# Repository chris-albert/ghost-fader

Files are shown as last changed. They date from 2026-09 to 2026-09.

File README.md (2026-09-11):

# Ghost Fader

USB-MIDI-controlled volume and pan for two balanced 1/4" line channels. Balanced in, always-balanced out, one input becomes stereo automatically. Bus-powered Seeed XIAO RP2040 plus a 2x2 gain matrix of PGA2310 attenuators. Revision D: USB only, no DIN jack, no DC jack; the audio side is galvanically isolated from the computer. A TI ISO7762F carries the four control lines and two sense lines across a split in the ground pours, the DC-DC module is the only power path across it, and a 78L05 makes the PGA logic supply on the audio side. About $6 of parts on top of rev C (XIAO RP2040, Traco TBA 2-0522).

The full schematic package (block diagram, five sheets, level budget, USB power budget, MIDI map, build order) is published at https://chris-albert.github.io/ghost-fader/ (source: `docs/index.html`). This file is the short version.

## Signal chain

```
J1/J2 TRS in -> THAT 1246 (bal->SE, -6 dB) -> 2x PGA2310 (2x2 matrix, 4 gains)
             -> OPA1642 summers (non-inverting, x2) -> THAT 1646 (SE->bal, +6 dB) -> J3/J4 TRS out
```

- Net gain balanced-to-balanced is 0 dB at PGA code 192. PGA range is +31.5 to -95.5 dB in 0.5 dB steps, plus hard mute.
- A TS plug on an input grounds the ring, so unbalanced sources need no switch. A TS plug on an output is handled by the cross-coupled 1646.
- Plug sense: each input jack's ring-normal contact is pulled up to +5VA by 100 k and read by the XIAO (D0, D1) through the isolator. Tip-normal is grounded.
- Matrix: U3 carries the direct paths (L->L, R->R), U4 the cross paths (L->R, R->L). Mono mode pans the L input across both outputs with a constant-power law; stereo mode uses balance.

## Power

Everything runs from the USB cable. There is no external power supply, DC jack or wall adapter. The XIAO's 5V pin is USB VBUS straight through, so it exports the bus 5 V. That feeds PS1, a small isolated 5 V -> +/-12 V DC-DC converter soldered to the board (Traco TBA 2-0522, 2 W, SIP-7), for the analog stages. The PGA2310 logic supply and the audio side of the isolator run on +5VA, made from +12 V by U10, a 78L05, so nothing on the audio side references the USB ground.

PS1 is unregulated: the rails follow the USB voltage and the load, from about +/-11 V on a sagging port to about +/-14 V at 5.25 V and light load. Every part on the rails is rated for that (the PGA2310 absolute maximum is 16 V, which is why the +/-15 V TBA 2-0523 is not used). Headroom at +/-12 V is about 2 dB less than on +/-15 V: the output driver clips near +22 dBu instead of +24. Total rail capacitance, about 120 uF per rail, stays under the 220 uF the TBA 2 allows.

| Load | Current at 5 V |
|---|---|
| XIAO RP2040, isolator side 1 | ~35 mA |
| PS1 delivering ~55 mA on +12 V (analog ~40 mA plus U10 ~15 mA) and ~40 mA on -12 V, at ~80 % | ~230 mA |
| LED | ~2 mA |
| Total | ~265 mA typical, ~330 mA worst case |

USB 2.0 ports allow 500 mA; USB 3 / USB-C ports allow 900 mA or more. Use a real port or a powered hub and a data cable (not charge-only).

Ground: there are two. GND_USB is the XIAO, its USB-C shell, the DIP switch, the LED, the ferrite, the reservoir cap, the isolator's side 1 and the DC-DC input. GND is everything audio, the PGA logic, the isolator's side 2 and the DC-DC output. They meet only through C45, a 1 nF cap that gives the converter's switching noise a local return so it does not radiate as common mode, and R17, 1 M, which stops the audio side drifting when nothing is plugged in. So the audio ground follows whatever gear is plugged into the jacks, the way a transformer-isolated DI does, and the computer's ground noise never enters the box. The isolator is the F (fail-safe low) part: when the XIAO is unpowered its outputs sit low, so the PGAs stay muted until the firmware is up.

For that to hold in the box, the XIAO's USB-C shell must not touch the enclosure: the enclosure belongs to the audio ground (bond it to the jack sleeves or to the PS1 Common pad with a wire, since the NRJ6HF bushings are plastic), so use a plastic bezel or a clearance cutout for the USB-C, not a metal-to-metal fit.

## XIAO RP2040 pins

| Pin | Signal |
|---|---|
| USB-C | MIDI in (class-compliant, TinyUSB) and 5 V in |
| 5V | USB 5 V out to FB1, PS1 |
| 3V3 | Isolator side 1 (U8 VCC1) |
| D0, D1 (GP26, GP27) | SENSE_L, SENSE_R through U8 (100 k pull-ups to +5VA on the audio side, internal pull-up off) |
| D2-D5 (GP28, GP29, GP6, GP7) | MIDI channel DIP, INPUT_PULLUP |
| D6 (GP0) | /MUTE to both PGA2310 through U8 (10 k pull-down on the PGA side mutes at boot) |
| D7 (GP1) | /CS through U8 |
| D8 (GP2, SCK) | SCLK through U8 |
| D9 (GP4, the MISO pin) | MIDI activity LED. Nothing comes back from the PGAs, so bit-bang the frame or leave SPI RX unassigned |
| D10 (GP3, MOSI) | SDI of U3 through U8; U3 SDO chains to U4 SDI |

The schematic symbol numbers the XIAO's 14 pins as Seeed's footprint does: 1-7 down the left row from the USB end (D0-D6), 8-14 up the right row (D7-D10, 3V3, GND, 5V).

SPI frame: 32 bits per update, U4's 16-bit word first, then U3's. Each word is the right-channel byte then the left. Code = 192 + 2 * dB, 0 = mute.

## MIDI map (proposed)

| CC | Function |
|---|---|
| 7 | Volume, 127 = 0 dB, 40*log10(v/127) dB |
| 10 | Pan (mono: constant power; stereo: balance) |
| 14, 15 | L / R input trim, +/-12 dB, 64 = 0 dB |
| 85 | Mono sum on/off |
| 120 | Hard mute |

## Parts list

Prices are approximate single-piece USD.

| Ref | Qty | Part | Description | ~$ ea | Notes |
|---|---|---|---|---|---|
| U1, U2 | 2 | THAT 1246S08 | Balanced line receiver, -6 dB | 5.50 | Alt: TI INA137 |
| U3, U4 | 2 | TI PGA2310PA | Stereo volume control, +/-15 V, SPI, DIP-16 | 11.00 | PGA2310UA for SOIC. Not PGA2311 |
| U5 | 1 | TI OPA2134PA | Dual JFET op-amp, DIP-8 | 4.00 | Alt: NE5532P |
| U6, U7 | 2 | THAT 1646S08 | Cross-coupled balanced driver, +6 dB | 5.50 | Alt: TI DRV134 |
| U8 | 1 | TI ISO7762FDW | 6-channel digital isolator, 4 forward / 2 reverse, fail-safe low, SOIC-16W | 4.50 | Not the plain ISO7762 (defaults high, which would unmute the PGAs while the XIAO boots) |
| U9 | 1 | Seeed XIAO RP2040 | MCU with USB-C, class-compliant USB MIDI via TinyUSB | 5.00 | On header pins. Its 5V pin is USB VBUS and feeds the board |
| U10 | 1 | L78L05 | 5 V 100 mA regulator, TO-92, from +12 V | 0.30 | Makes +5VA on the audio side for the PGA logic and U8 side 2, about 15 mA |
| PS1 | 1 | Traco TBA 2-0522 | Board-mounted isolated DC-DC, 4.5-5.5 V in, +/-12 V 80 mA, 2 W, unregulated, SIP-7 | 5.00 | Fed from USB 5 V, not an external supply. Any industry-standard SIP-7 2 W +/-12 V module (Mornsun B0512, RECOM RB-0512D) has the same pinout. Not a +/-15 V part: unregulated rails would pass the PGA2310's 16 V maximum at light load |
| FB1 | 1 | Ferrite bead 600 R @ 100 MHz, >=1 A | Keeps switching noise off USB | 0.20 | |
| J1-J4 | 4 | Neutrik NRJ6HF | 1/4" TRS PCB jack, T and R switching | 3.00 | Switch contacts used on J1, J2 only |
| L1, L2 | 2 | 10 uH, >=300 mA | Rail filters | 0.40 | |
| SW1 | 1 | 4-way DIP | MIDI channel | 0.80 | |
| LED1 | 1 | 3 mm LED | Activity | 0.15 | |
| C3-C6, C17-C20 | 8 | 10 uF non-polar | C3-C6 coupling into PGA inputs, C17-C20 THAT 1646 sense caps | 0.40 | Nichicon UES |
| C1, C2, C7-C10, C15, C16 | 8 | 100 pF C0G | RF caps at every jack tip and ring | 0.10 | |
| C11 | 1 | 47 uF 10 V low-ESR | USB-side reservoir | 0.25 | |
| C12, C13 | 2 | 100 uF 25 V | Rail filters | 0.25 | |
| C14 | 1 | 10 uF | +5VA logic rail | 0.10 | |
| C21-C39, C44 | 20 | 100 nF X7R | One per supply pin; C37/C38 at U10, C39/C44 at U8 | 0.05 | |
| C45 | 1 | 1 nF 1 kV ceramic | Ground barrier cap, GND to GND_USB | 0.15 | Straddles the pour gap at PS1 |
| C40-C43 | 4 | 10 uF 25 V | +/-12 V bulk, input end and output end | 0.10 | |
| R2-R9 | 8 | 10 k 1% | Summing and feedback | 0.05 | |
| R10-R13 | 4 | 10 R | Output build-out | 0.05 | |
| R1, R14 | 2 | 100 k | Plug-sense pull-ups to +5VA | 0.05 | 100 k, not 1 M: U8's inputs leak up to 10 uA |
| R15, R16 | 2 | 10 k, 1 k | Mute pull-down, LED | 0.05 | |
| R17 | 1 | 1 M | Ground barrier bleed, GND to GND_USB | 0.05 | Straddles the pour gap |
| CABLE | 1 | USB A/C to USB-C data cable | Short and thick | 3.00 | |
| ENC | 1 | Hammond 1590BB | Die-cast enclosure | 12.00 | |
| PCB | 1 | 2-layer 108 x 80 mm | Gerbers in `hardware/gerbers/` | 10.00 | Corner notches clear the 1590BB lid-screw bosses |

Estimated total: about $116 per unit, or about $106 with the narrow board in a printed box instead of the 1590BB. Cost-down variant with one PGA2310 and a DG419 routing switch instead of the matrix: about $90, loses cross-feed and mono-sum.

## Full schematic

`hardware/kicad/` is a KiCad 9 project: root sheet plus input, matrix, output, control and power sheets, with a project symbol library (THAT 1246/1646, PGA2310, OPA2134, XIAO RP2040, TBA 2, ISO7762F, 78L05, the GND_USB power symbol) and a footprint for the XIAO on header pins; the TBA 2, the isolator and the regulator use KiCad's stock footprints. ERC passes with zero violations and the netlist (61 nets, 263 pins) has been checked pin-for-pin against `hardware/kicad/tools/check.py`. `bom.csv` is the KiCad BOM export. Rendered sheets and a PDF are in `docs/schematic/` and on the published page.

Every part has a footprint; the jacks use KiCad's stock Neutrik NRJ6HF horizontal footprint, whose pad names match the symbol. The schematic is generated by `hardware/kicad/tools/gen.py`; edit it in KiCad directly from here on, or edit the generator and rerun it (it needs KiCad's stock symbol libraries at the macOS install path).

## PCB

`hardware/kicad/ghost-fader.kicad_pcb` is a routed 2-layer board, 108 x 80 mm, DRC clean against the schematic (the only warnings are the jack noses' and the USB-C shell's silkscreen crossing the board edge, which is inherent to the footprints). Gerbers, Excellon drill file and drill map are in `hardware/gerbers/` and zipped as `hardware/ghost-fader-gerbers.zip`; upload the zip as-is to JLCPCB, PCBWay or OSH Park (2 layers, 1.6 mm, any finish). Renders are in `docs/pcb/` and on the published page.

Layout, rear edge at the top:

- The four jacks sit along one long edge, IN L, IN R, OUT L, OUT R at 19, 39, 68 and 90 mm from the left edge. Their threaded noses stick 1.5 mm past the board edge so the panel nuts have thread to bite. Drill the enclosure wall on those centres.
- Signal flows down and around: jacks -> RF caps -> THAT 1246 receivers (rotated so the inputs face the jacks) -> coupling caps -> the two PGA2310s side by side, analog pins facing up and SPI pins facing the XIAO -> OPA2134 summer and its resistors on the right -> THAT 1646 drivers under the output jacks with their sense caps and build-outs.
- The front-left corner is the USB ground island: the XIAO with its USB-C face flush with the front edge (cut a slot in the front wall for the plug, and keep the shell off the metal), the DIP switch to its right, the LED and its resistor in the left column, the ferrite and reservoir cap, and the input end of the DC-DC. The isolator U8 lies across the top edge of the island with its USB row inside and its audio row outside; PS1 lies across the island's right edge the same way. The barrier parts C45 and R17 straddle the gap in the left column. The 78L05, rail filters and the rest of the power section are front-centre on the audio side, the far corner from the input receivers.
- Every decoupling cap is within a few mm of its supply pin. The +/-12 V bulk pairs are at the input end (C40/C41, between J2 and J3) and the output end (C42/C43, right edge).
- Two ground pours on both layers, audio and USB, separated by a 2 mm gap with no copper. A rule area over the gap keeps the router out, and only U8, PS1, C45 and R17 cross it; a script check confirms no track or via enters the gap. Each pour is stitched by the ground tracks the router laid first, so the schematic's "star at PS1 COM" becomes a plane on the audio side. Power nets are 0.6 mm tracks, signals 0.3 mm, 0.25 mm clearance; anyone can fab it.
- The board is held by the four jack nuts. The corners are notched 7.5 x 6.5 mm to clear the 1590BB lid-screw bosses. Check fit against the actual box before ordering: the inside is about 112 x 86 mm at the base, so there is 2 to 3 mm each way.

The LED is a through-hole 3 mm on the left edge near the front corner; bend it out through a hole in the left wall, or toward the front panel, or fit a light pipe. To regenerate the board from the schematic (placement is a table in `tools/build_pcb.py`, routing is Freerouting):

```
cd hardware/kicad
kicad-cli sch export netlist --format kicadsexpr -o /tmp/gf.net ghost-fader.kicad_sch
<KiCad python3> tools/build_pcb.py /tmp/gf.net          # placement, outline, pours, rules
<KiCad python3> tools/route.py ghost-fader.kicad_pcb <freerouting launcher or jar>
kicad-cli pcb drc --severity-all --schematic-parity -o /tmp/drc.rpt ghost-fader.kicad_pcb
```

`<KiCad python3>` is the interpreter bundled with KiCad (on macOS `/Applications/KiCad/KiCad.app/Contents/Frameworks/Python.framework/Versions/Current/bin/python3`), which has the `pcbnew` module. Freerouting 1.9 was used; 2.4 routes the same board but writes an empty session file from the command line.

## Narrow in-line PCB

`hardware/kicad/ghost-fader-narrow.kicad_pcb` is the same schematic on a second, independent board shaped for a signal chain: 207 x 38 mm, inputs on the right end, outputs on the left, the XIAO's USB-C out of the middle of the rear long edge, so the box sits in-line like a pedal. It is as narrow as two side-by-side jacks allow: the NRJ6HF jacks sit on an 18 mm pitch (34.8 mm) plus edge clearance. The XIAO (21 mm long) lies across the board with its USB-C at the rear edge. It needs a 3D-printed box: about 40 x 210 mm inside, a ledge under the long board edges, two jack holes in each end wall on the jack centres (10 and 28 mm from the rear edge of the board, at the NRJ6HF bushing height), a USB-C slot and a 3 mm LED hole in the rear wall. No mounting holes; the four jack nuts hold the board. Routed, DRC clean against the schematic (the same jack-nose silkscreen warnings as the main board), 0.6 mm power tracks, 0.3 mm signals, split ground pours both sides. The USB ground island is a pocket on the rear edge, x 104 to 141 mm by 28 mm deep, holding the XIAO, LED, DIP switch, ferrite and reservoir; the audio ground wraps under it so the rails and audio pass from the input end to the output end. U8 straddles the pocket's left wall, PS1 its right wall. Gerbers in `hardware/gerbers-narrow/` and `hardware/ghost-fader-narrow-gerbers.zip`; renders in `docs/pcb-narrow/`. The 1590BB board above is unchanged.

Everything runs in columns along the length, left to right: output jacks, RF caps, drivers with their sense caps stacked, build-outs and 100n, summer with its resistors, coupling caps, the two PGA2310s stacked across the board with their SPI rows facing each other, the isolator, the LED and XIAO, DIP switch, ferrite and reservoir over the barrier parts and +/-12 V bulk caps, DC-DC, 78L05 and rail filters, receivers with the sense pull-ups, bulk caps, RF caps, input jacks. The LED sits at the rear edge just left of the XIAO, about 107 mm from the left end. Most reference labels sit on the part bodies because there is no room beside them; they read on the bare board. Parts come within 1 mm of the long edges, so give the printed walls clearance above the board edge.

To regenerate: same steps as above with `tools/build_pcb_narrow.py` in place of `tools/build_pcb.py` and `ghost-fader-narrow.kicad_pcb` as the board.

## Notes

- The overview sheets label IC pins by function. The KiCad schematic in `hardware/kicad/` has the real pin numbers and is the one to lay out from.
- The PGAs are driven at 5 V by the isolator's outputs. Never route a PGA SDO (5 V) back toward the XIAO: the RP2040 is not 5 V tolerant, and nothing crosses U8 in that direction except the two sense lines.
- Ground is two pours on both layers with a 2 mm gap; the DC-DC is at the far end of the board from the input receivers.

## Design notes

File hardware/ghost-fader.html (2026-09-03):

# Ghost Fader

USB-MIDI-controlled volume and pan for two balanced ¼″ line channels. Balanced in, always-balanced out, one input becomes stereo automatically. Bus-powered Teensy 4.0 plus a 2×2 gain matrix of PGA2310 attenuators.

Sheet set

0 block · 1 input · 2 matrix · 3 output · 4 control · 5 power

Revision

B · 2026-09-02 · USB only

Signal level

+4 dBu nominal, +22 dBu peak

Rails

USB 5 V → isolated ±15 V analog · 5 V logic · 3.3 V Teensy

Inputs2 × ¼″ TRS, balanced or unbalanced, 48 kΩ differential

Outputs2 × ¼″ TRS, cross-coupled balanced, tolerates TS loads

Gain range+31.5 dB to −95.5 dB in 0.5 dB steps, hard mute

ControlUSB MIDI, class-compliant, channel set by DIP switch

Mono → stereoJack switch detects a missing R plug; firmware pans the L signal

PowerUSB bus power, ≈ 0.4 A at 5 V, one cable does everything

Sheet 0 · How it works

Each input goes through a differential line receiver that turns the balanced pair into a clean single-ended signal and rejects cable noise. A plain TS plug just grounds the cold side, so unbalanced sources work with no switch. From there the two signals feed four digitally controlled attenuators arranged as a 2×2 matrix: any input can reach either output at any level. Two op-amp summers add the contributions, and cross-coupled balanced drivers put a true balanced signal on each output jack.

The Teensy shows up on the computer as a class-compliant USB MIDI device, works out four gains from volume, pan, and whether the R jack has a plug in it, and writes them over SPI. Because pan and mono-to-stereo are just numbers in the matrix, there is no analog routing switch, no relay click, and a stereo source can be balanced or genuinely image-shifted. The same USB cable powers the box: an isolated DC-DC module turns the 5 V bus into the ±15 V analog rails.

audiocontrolpowerplug sense

Block diagram. Audio stays analog end to end; the Teensy only sets gains. The computer's USB port supplies both MIDI and power; PS1 regenerates clean, isolated ±15 V rails from the noisy 5 V bus.

### Why these parts

- PGA2310, not a digital pot. Digital pots run on 5 V and clip around 1.5 V peak. The PGA2310 runs on ±15 V, handles 9.5 Vrms, steps in 0.5 dB, and changes gain only at zero crossings, so there is no zipper noise. Its logic inputs are TTL-threshold, so the 3.3 V Teensy drives it directly.
- THAT 1246 / 1646 pair. The receiver drops 6 dB and the driver adds it back, so balanced-to-balanced is unity gain and the PGA sees a signal that fits comfortably. The 1646 is cross-coupled, so a TS plug on an output still gets the full signal instead of half.
- Matrix instead of a routing switch. Four gains cost one extra PGA2310 but remove every analog switch, and they make mono-to-stereo, balance, true pan and mono-sum pure firmware.

### Cost-down option

If cross-feed and mono-sum do not matter, drop U4 and the summers and put a DG419 analog switch in front of the second PGA channel: it picks the R receiver when a plug is present and the L receiver when it is not. That saves roughly $18 and one op-amp, at the cost of a small click on plug insertion unless firmware mutes around it.

### Pin numbering

Sheets 1 to 5 label IC pins by function, not number. Take pin numbers from the current datasheet for the package you order when you lay out the board. Every supply pin gets a 100 nF ceramic right at the pin; those are listed in the parts list but not drawn.

Sheet 1 · Input receiver, one of two

Balanced receiver with plug sense. A TS plug shorts ring to sleeve, so the receiver simply sees tip against ground. Unplugged, the ring spring rests on RN and the receiver's 24 kΩ input pulls the sense line low; any plug lifts it and R1 pulls the line high. TN grounds the idle tip. Channel R (J2, U2, C4–C6, R14) is identical, sense goes to Teensy pin 3, and its output is net R_SE.

Sheet 2 · Gain matrix and summers

2×2 matrix. Each receiver drives two 10 kΩ PGA inputs; each summer takes one direct and one cross path. The non-inverting summer keeps absolute polarity. Dots are junctions; crossings without dots do not connect. The Teensy clocks 32 bits per update: U4's word first, then U3's.

Gain | Chip · channel | Takes | Feeds | Stereo (R plugged) | Mono (R empty)
a | U3 · L | L_SE | L_SUM | vol × balance-left | vol × cos θ
d | U3 · R | R_SE | R_SUM | vol × balance-right | mute
c | U4 · L | L_SE | R_SUM | mute | vol × sin θ
b | U4 · R | R_SE | L_SUM | mute | mute

Sheet 3 · Balanced output driver, one of two

Cross-coupled balanced output. If a TS cable grounds the ring, the 1646 senses it and doubles the tip drive, so an unbalanced destination still receives the full level. Channel R (U7, J4, R12, R13, C9, C10) is identical and takes R_SUM.

Sheet 4 · Teensy, USB, switches

Control. The Teensy's own micro-B connector is the only port: MIDI comes in as a class-compliant USB device and the bus 5 V leaves through the VIN pin. R15 holds both PGAs muted until the firmware has written its first gains, which kills the power-on thump. DIP switch bits use the Teensy's internal pull-ups; closed = 0.

Teensy 4.0 power. Leave the VUSB–VIN jumper pad on the underside intact. With it in place the VIN pin carries the USB 5 V out to the rest of the board, which is exactly what sheet 5 needs. In firmware, drop the CPU clock to 150 MHz with set_arm_clock(); it halves the Teensy's draw and this job needs nothing like 600 MHz.

Sheet 5 · Power

Power. Everything runs from the USB 5 V that the Teensy passes out on VIN. PS1 is an isolated module, so the analog rails are regenerated rather than filtered from the bus. All grounds meet once, at PS1's COM pin: analog ground, PGA DGND and Teensy ground. Keep PS1 at the far end of the board from the input receivers.

### USB power budget

Load | Current at 5 V | Note
Teensy 4.0 | ≈ 100 mA | ≈ 50 mA with the clock set to 150 MHz
PS1 supplying ≈ 35 mA on each ±15 V rail | ≈ 260 mA | THAT parts, two PGA2310, OPA1642; module about 80 % efficient
PGA2310 logic, LED | ≈ 10 mA
Total | ≈ 370 mA typical · ≈ 450 mA worst case | USB 2.0 port allows 500 mA; USB 3 / USB-C ports allow 900 mA or more

So yes, bus power works, with three conditions:

- Plug into a real port or a powered hub. An unpowered hub shares one 500 mA allowance across every device on it, and a laptop running on battery may throttle its ports.
- Drop the Teensy clock in firmware. That alone buys back about 50 mA of margin.
- Expect the audio ground to be tied to the computer's ground. PS1 isolates the rails, but the Teensy and PGA share a ground, so the box's audio ground meets USB ground. If the same computer also drives the PA through an audio interface this is one ground and no problem. If the computer is only sending MIDI while the synths go to a separately earthed mixer, a hum loop is possible. The cure, if you hear it, is a TI ISO7762 digital isolator on the four SPI/mute lines and the two sense lines, with the PGA's 5 V logic taken from +15 V through a 78L05 instead of from USB. That floats the entire analog side from the computer for about $6 in parts.

Level budget

Point in chain | Nominal | Peak | Limit there
Balanced input | +4 dBu · 1.23 Vrms | +22 dBu · 9.8 Vrms | THAT 1246 common-mode ±13 V on ±15 V rails
After U1 (−6 dB) | 0.61 Vrms | 4.9 Vrms | PGA2310 full scale 9.5 Vrms, so 5.7 dB spare at peak
After summer (×2 on a ½ divider) | 0.61 Vrms | 4.9 Vrms | OPA1642 swings ±13 V
Balanced output (+6 dB differential) | +4 dBu | +22 dBu | THAT 1646 clips near +24 dBu on ±15 V
Unbalanced TS source at 0 dBV | 0 dBV in → 0 dBV differential out | | Tip-only destination sees −6 dB; use the trim CC

Net gain balanced-in to balanced-out is 0 dB with the PGA at code 192. The PGA can add up to 31.5 dB, so a quiet −10 dBV consumer source can be brought up to line level without touching hardware.

MIDI and firmware map

CC | Function | Mapping
7 | Volume | 127 = 0 dB, 0 = mute, 40·log10(v/127) dB between
10 | Pan | 64 = center. Mono: constant-power pan. Stereo: balance, center is 0 dB both sides
14 | L input trim | ±12 dB, 64 = 0 dB (lift unbalanced sources)
15 | R input trim | ±12 dB, 64 = 0 dB
85 | Mono sum | ≥ 64: both inputs summed at −6 dB each, then panned
120 | Mute | Any value: hard mute via /MUTE pin

Teensy pin | Signal | Goes to
USB | MIDI in, 5 V in | host computer
VIN | USB 5 V out | FB1, PS1, PGA VD
2, 3 | SENSE_L, SENSE_R | J1, J2 ring-normal
4–7 | MIDI channel | SW1, INPUT_PULLUP
8 | Activity LED | R16, LED1
9 | /MUTE | U3, U4
10 | /CS | U3, U4
11 · MOSI | SDI | U3 (chains to U4)
13 · SCK | SCLK | U3, U4

Gain code per PGA channel is N = 192 + 2·dB, clamped to 0–255, with 0 meaning mute. Each PGA takes a 16-bit word, right channel byte first. With two chips daisy-chained the Teensy sends U4's word, then U3's, in one chip-select frame:

// a,d live in U3 (L,R); c,b live in U4 (L,R)
uint8_t code(float dB){ if (dB < -95.5f) return 0; return (uint8_t)constrain(192 + 2*dB, 1, 255); }

void writeMatrix(float a, float b, float c, float d){
  SPI.beginTransaction(SPISettings(1000000, MSBFIRST, SPI_MODE0));
  digitalWrite(CS, LOW);
  SPI.transfer(code(b)); SPI.transfer(code(c));   // U4: R byte, then L byte  (shifts through to U4)
  SPI.transfer(code(d)); SPI.transfer(code(a));   // U3: R byte, then L byte
  digitalWrite(CS, HIGH);
  SPI.endTransaction();
}

// mono mode: theta = pan/127 * PI/2;  a = vol*cos(theta); c = vol*sin(theta); b = d = mute

Parts list

Ref | Qty | Part | Description | ≈ $ ea | Alternates and notes
Audio
U1, U2 | 2 | THAT 1246S08 | Balanced line receiver, −6 dB, SO-8 | 5.50 | TI INA137UA is drop-in-similar. THAT 1240 (0 dB) if you would rather pad in firmware
U3, U4 | 2 | TI PGA2310UA | Stereo volume control, ±15 V analog, SPI, SOIC-16 | 11.00 | PGA2310PA is the DIP-16 for breadboarding. Not PGA2311 (±5 V, too little headroom)
U5 | 1 | TI OPA1642AID | Dual JFET audio op-amp, SOIC-8 | 4.00 | NE5532 works, slightly more noise
U6, U7 | 2 | THAT 1646S08 | Cross-coupled balanced line driver, +6 dB, SO-8 | 5.50 | TI DRV134UA is the equivalent
J1, J2 | 2 | Neutrik NRJ6HF | ¼″ TRS PCB jack, horizontal, tip and ring switching contacts | 3.00 | Any TRS jack with a ring-normal contact; the switch is the plug sense
J3, J4 | 2 | Neutrik NRJ6HF | ¼″ TRS PCB jack (switch contacts unused) | 3.00 | Same part keeps the panel uniform
C3–C6 | 4 | 10 µF non-polar | Bipolar electrolytic, 25 V, coupling into PGA | 0.40 | Nichicon UES / MUSE ES, or 4.7 µF film
C1, C2, C7–C10 (+2 for J2) | 8 | 100 pF C0G | RF caps at every jack tip and ring | 0.10 | Return to chassis / sleeve, shortest path
R2–R9 | 8 | 10 kΩ 1% | Summing and feedback, metal film | 0.05 | Match within a summer for a clean mono sum
R10–R13 | 4 | 10 Ω | Output build-out | 0.05
R1, R14 | 2 | 1 MΩ | Plug-sense pull-ups to 3.3 V | 0.05 | Do not enable the Teensy internal pull-up on pins 2, 3
Control
U9 | 1 | PJRC Teensy 4.0 | MCU, USB MIDI, with header pins | 24.00 | Leave the VUSB–VIN pad intact; VIN feeds the board
R15, R16 | 2 | 10 kΩ, 1 kΩ | Mute pull-down, LED series | 0.05
SW1 | 1 | 4-way DIP switch | MIDI channel 1–16 | 0.80
LED1 | 1 | 3 mm LED | MIDI activity | 0.15
CABLE | 1 | USB A or C to micro-B | Data cable, not a charge-only cable | 3.00 | Short and thick keeps the 5 V drop small
Power
PS1 | 1 | Traco TMR 3-0523 | Isolated DC-DC, 4.5–9 V in, ±15 V 100 mA out, 3 W | 22.00 | Any 2–3 W ±15 V module with 5 V nominal input (Recom, Murata, Mornsun). Budget ≈ 50 mA per rail
FB1 | 1 | Ferrite bead, 600 Ω @ 100 MHz, ≥ 1 A | Keeps converter switching noise off the USB line | 0.20
L1, L2 | 2 | 10 µH, ≥300 mA | Rail filter inductors | 0.40
C11 | 1 | 47 µF 10 V low-ESR | USB-side reservoir for PS1 | 0.25 | Keep it modest; USB frowns on big inrush
C12, C13 | 2 | 100 µF 25 V | ±15 V rail filters | 0.25
C14 | 1 | 10 µF | 5 V logic rail | 0.10
Cdec | 12 | 100 nF X7R | One at every supply pin of U1–U7, PS1 | 0.05 | Plus 10 µF per rail near each THAT part
Mechanical
ENC | 1 | Hammond 1590BB | Die-cast aluminium, 119 × 94 × 34 mm | 12.00 | 1590DD if you want a hand-solderable spread
PCB | 1 | 2-layer, ≈ 100 × 80 mm | Ground pour, jacks on one edge, DC-DC on the far edge | 10.00 | 5 boards from JLCPCB or OSH Park
Estimated total, one unit at single-piece prices | | | | ≈ 145 | Cost-down variant (one PGA2310 + DG419): ≈ 125

Build order and checks

1. Power only. Fit U9, FB1, C11, PS1 and the filters, nothing else. Plug the USB cable into the computer and confirm +15 / −15 V with no load and with a 330 Ω test load on each rail. Put an inline USB current meter on the cable: expect well under 450 mA.
2. Teensy. Load a sketch that sets the clock to 150 MHz and blinks LED1 on any MIDI message. Check the box appears as a MIDI device on the computer and that the DIP switch selects the channel.
3. Receivers and drivers. Fit U1, U2, U6, U7 and jacks. Temporarily jumper L_SE to L_SUM: a balanced test tone should come out at unity gain, and a TS plug on the input should still produce a balanced output.
4. Matrix. Remove the jumper, fit U3, U4, U5. Write code 192 to all four gains and confirm unity, then mute (0) and confirm silence. Change gains while a tone is playing: with ZCEN high there should be no click.
5. Plug sense. Watch pins 2 and 3 while inserting TS and TRS plugs; both must read high with any plug and low when empty.

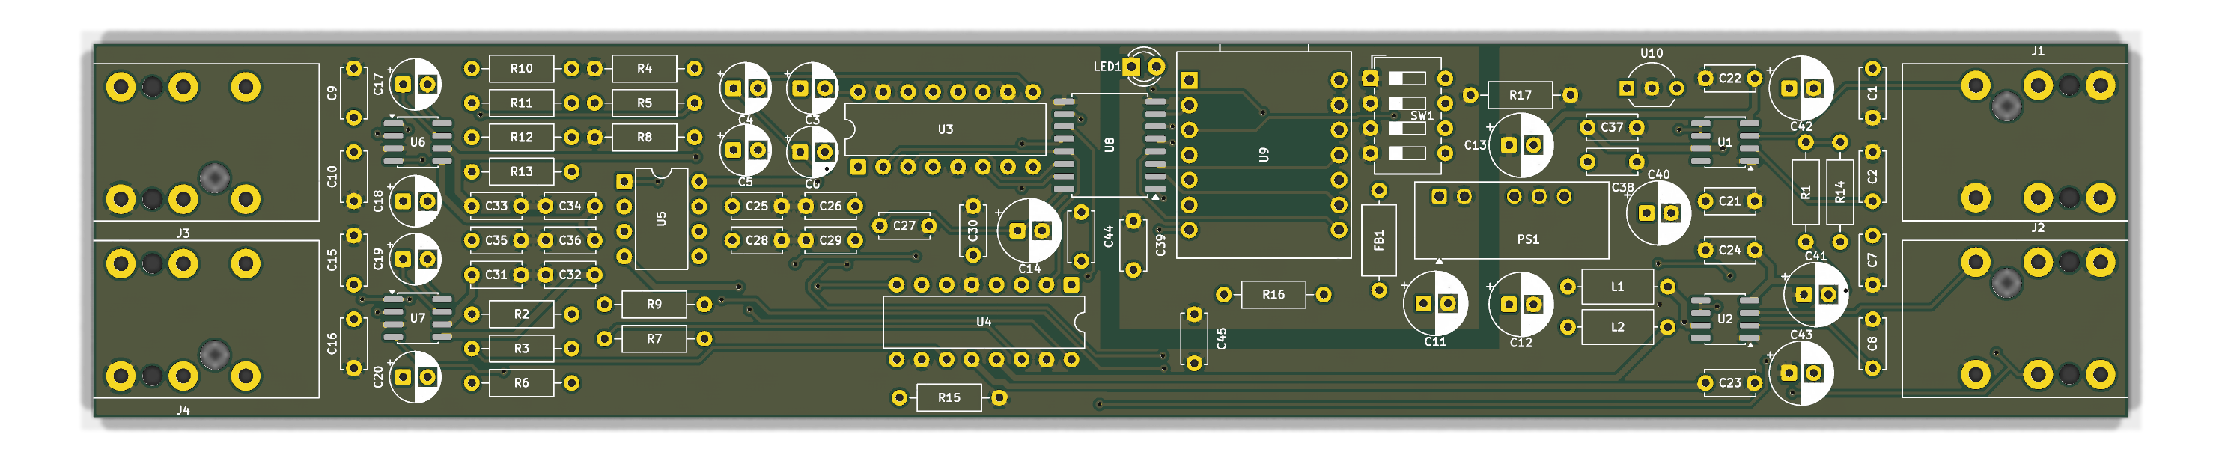
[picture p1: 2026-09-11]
docs/pcb-narrow/top.png

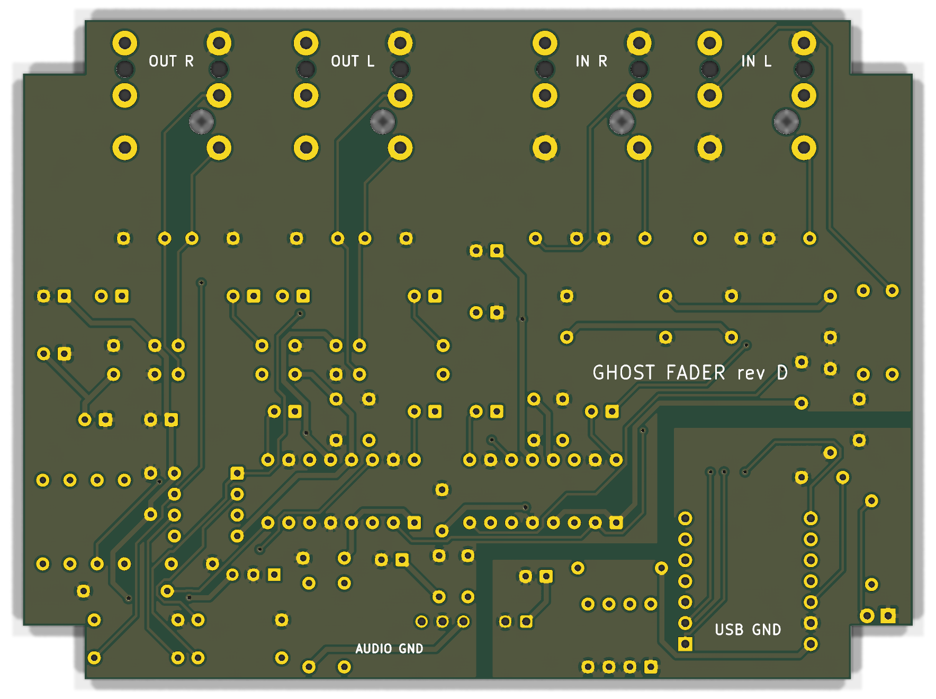
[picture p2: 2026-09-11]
docs/pcb/bottom.png

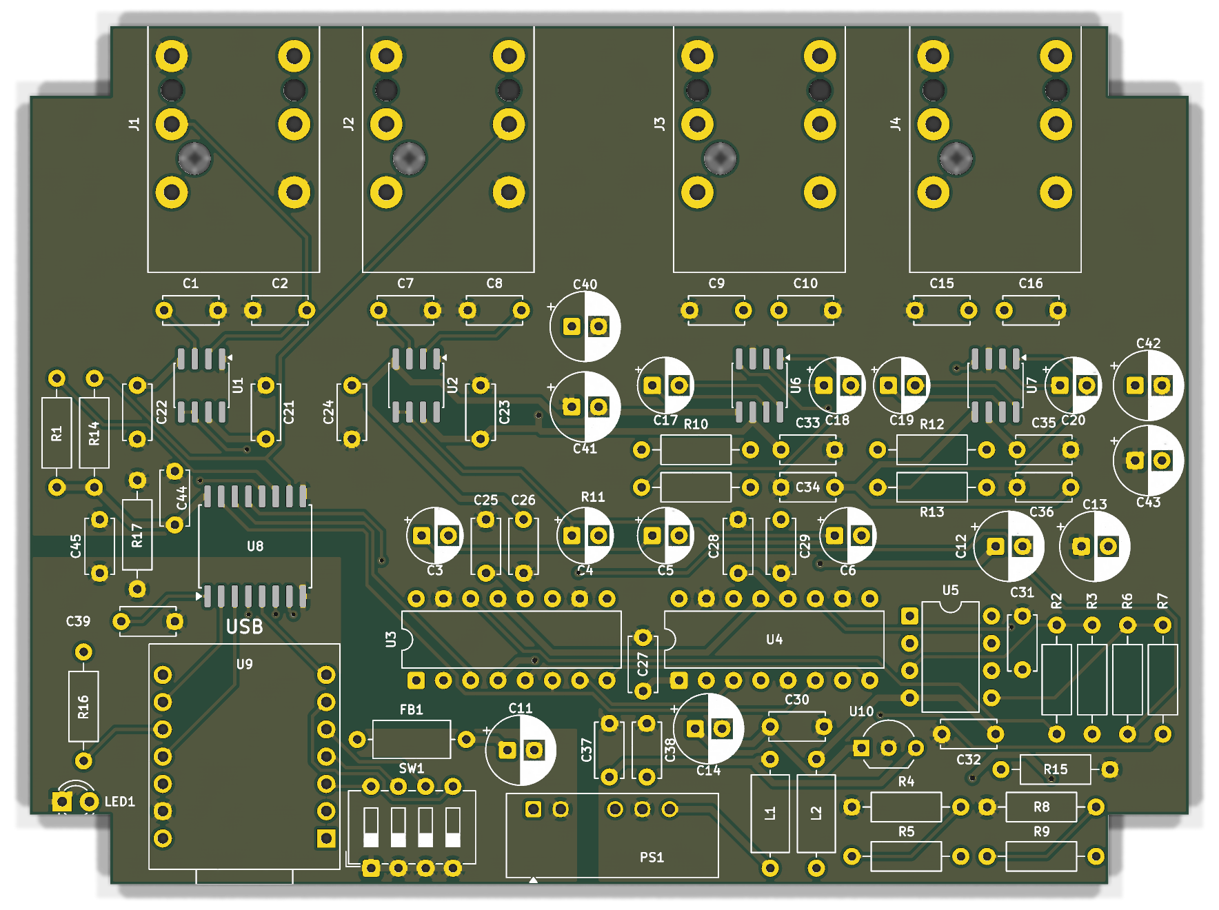
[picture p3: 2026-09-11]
docs/pcb/top.png

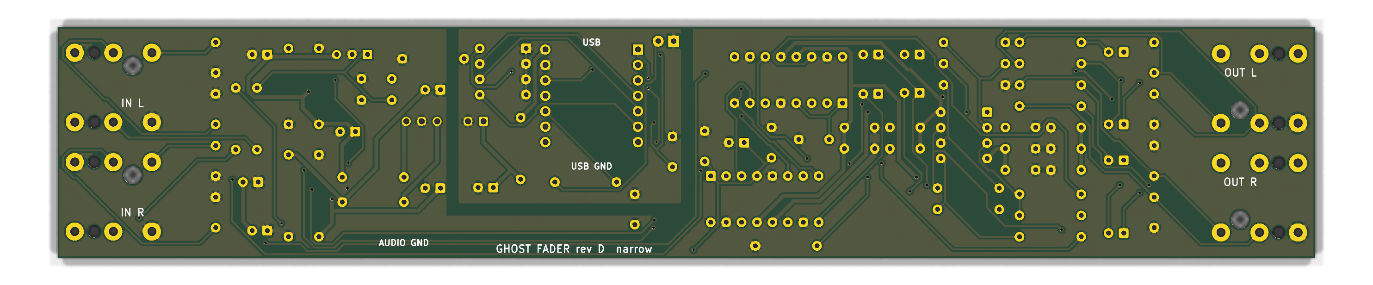
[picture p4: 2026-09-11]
docs/pcb-narrow/bottom.png

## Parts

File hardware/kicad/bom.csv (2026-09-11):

Reference | Value | Footprint | QUANTITY
C1,C2,C7-C10,C15,C16 | 100p C0G | Capacitor_THT:C_Disc_D5.0mm_W2.5mm_P5.00mm | 8
C3-C6,C17-C20 | 10u NP | Capacitor_THT:CP_Radial_D5.0mm_P2.50mm | 8
C11 | 47u low-ESR | Capacitor_THT:CP_Radial_D6.3mm_P2.50mm | 1
C12,C13 | 100u 25V | Capacitor_THT:CP_Radial_D6.3mm_P2.50mm | 2
C14,C40-C43 | 10u | Capacitor_THT:CP_Radial_D6.3mm_P2.50mm | 5
C21-C39,C44 | 100n | Capacitor_THT:C_Disc_D5.0mm_W2.5mm_P5.00mm | 20
C45 | 1n 1kV | Capacitor_THT:C_Disc_D5.0mm_W2.5mm_P5.00mm | 1
FB1 | 600R@100MHz 1A | Inductor_THT:L_Axial_L7.0mm_D3.3mm_P10.16mm_Horizontal_Fastron_MICC | 1
J1-J4 | NRJ6HF | Connector_Audio:Jack_6.35mm_Neutrik_NRJ6HF_Horizontal | 4
L1,L2 | 10uH 300mA | Inductor_THT:L_Axial_L7.0mm_D3.3mm_P10.16mm_Horizontal_Fastron_MICC | 2
LED1 | MIDI act | LED_THT:LED_D3.0mm | 1
PS1 | TBA 2-0522 | Converter_DCDC:Converter_DCDC_TRACO_TBA2-xxxx_Dual_THT | 1
R1,R14 | 100k | Resistor_THT:R_Axial_DIN0207_L6.3mm_D2.5mm_P10.16mm_Horizontal | 2
R2-R9,R15 | 10k | Resistor_THT:R_Axial_DIN0207_L6.3mm_D2.5mm_P10.16mm_Horizontal | 9
R10-R13 | 10R | Resistor_THT:R_Axial_DIN0207_L6.3mm_D2.5mm_P10.16mm_Horizontal | 4
R16 | 1k | Resistor_THT:R_Axial_DIN0207_L6.3mm_D2.5mm_P10.16mm_Horizontal | 1
R17 | 1M | Resistor_THT:R_Axial_DIN0207_L6.3mm_D2.5mm_P10.16mm_Horizontal | 1
SW1 | MIDI channel | Button_Switch_THT:SW_DIP_SPSTx04_Slide_6.7x11.72mm_W7.62mm_P2.54mm_LowProfile | 1
U1,U2 | THAT1246S08 | Package_SO:SOIC-8_3.9x4.9mm_P1.27mm | 2
U3,U4 | PGA2310PA | Package_DIP:DIP-16_W7.62mm | 2
U5 | OPA2134PA | Package_DIP:DIP-8_W7.62mm | 1
U6,U7 | THAT1646S08 | Package_SO:SOIC-8_3.9x4.9mm_P1.27mm | 2
U8 | ISO7762FDW | Package_SO:SOIC-16W_7.5x10.3mm_P1.27mm | 1
U9 | XIAO RP2040 | GhostFader:XIAO_RP2040_THT | 1
U10 | L78L05 | Package_TO_SOT_THT:TO-92_Inline_Wide | 1

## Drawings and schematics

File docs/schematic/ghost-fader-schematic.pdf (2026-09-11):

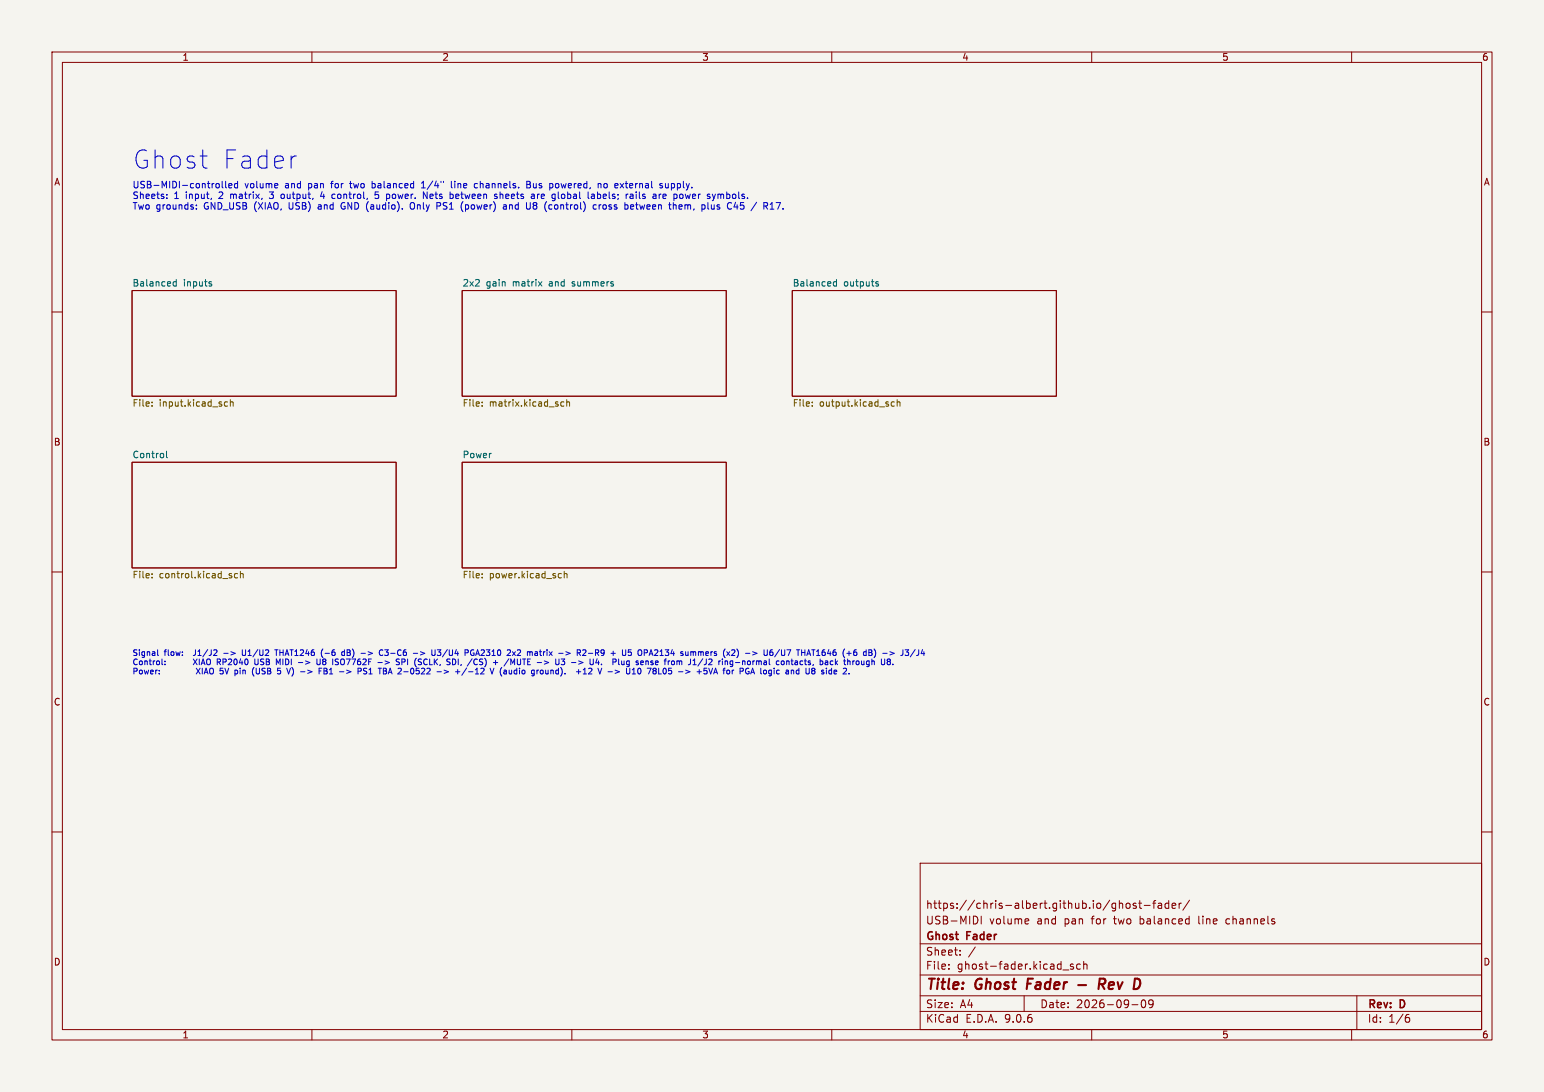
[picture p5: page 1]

Id: 1/6 Title: Ghost Fader - Rev D

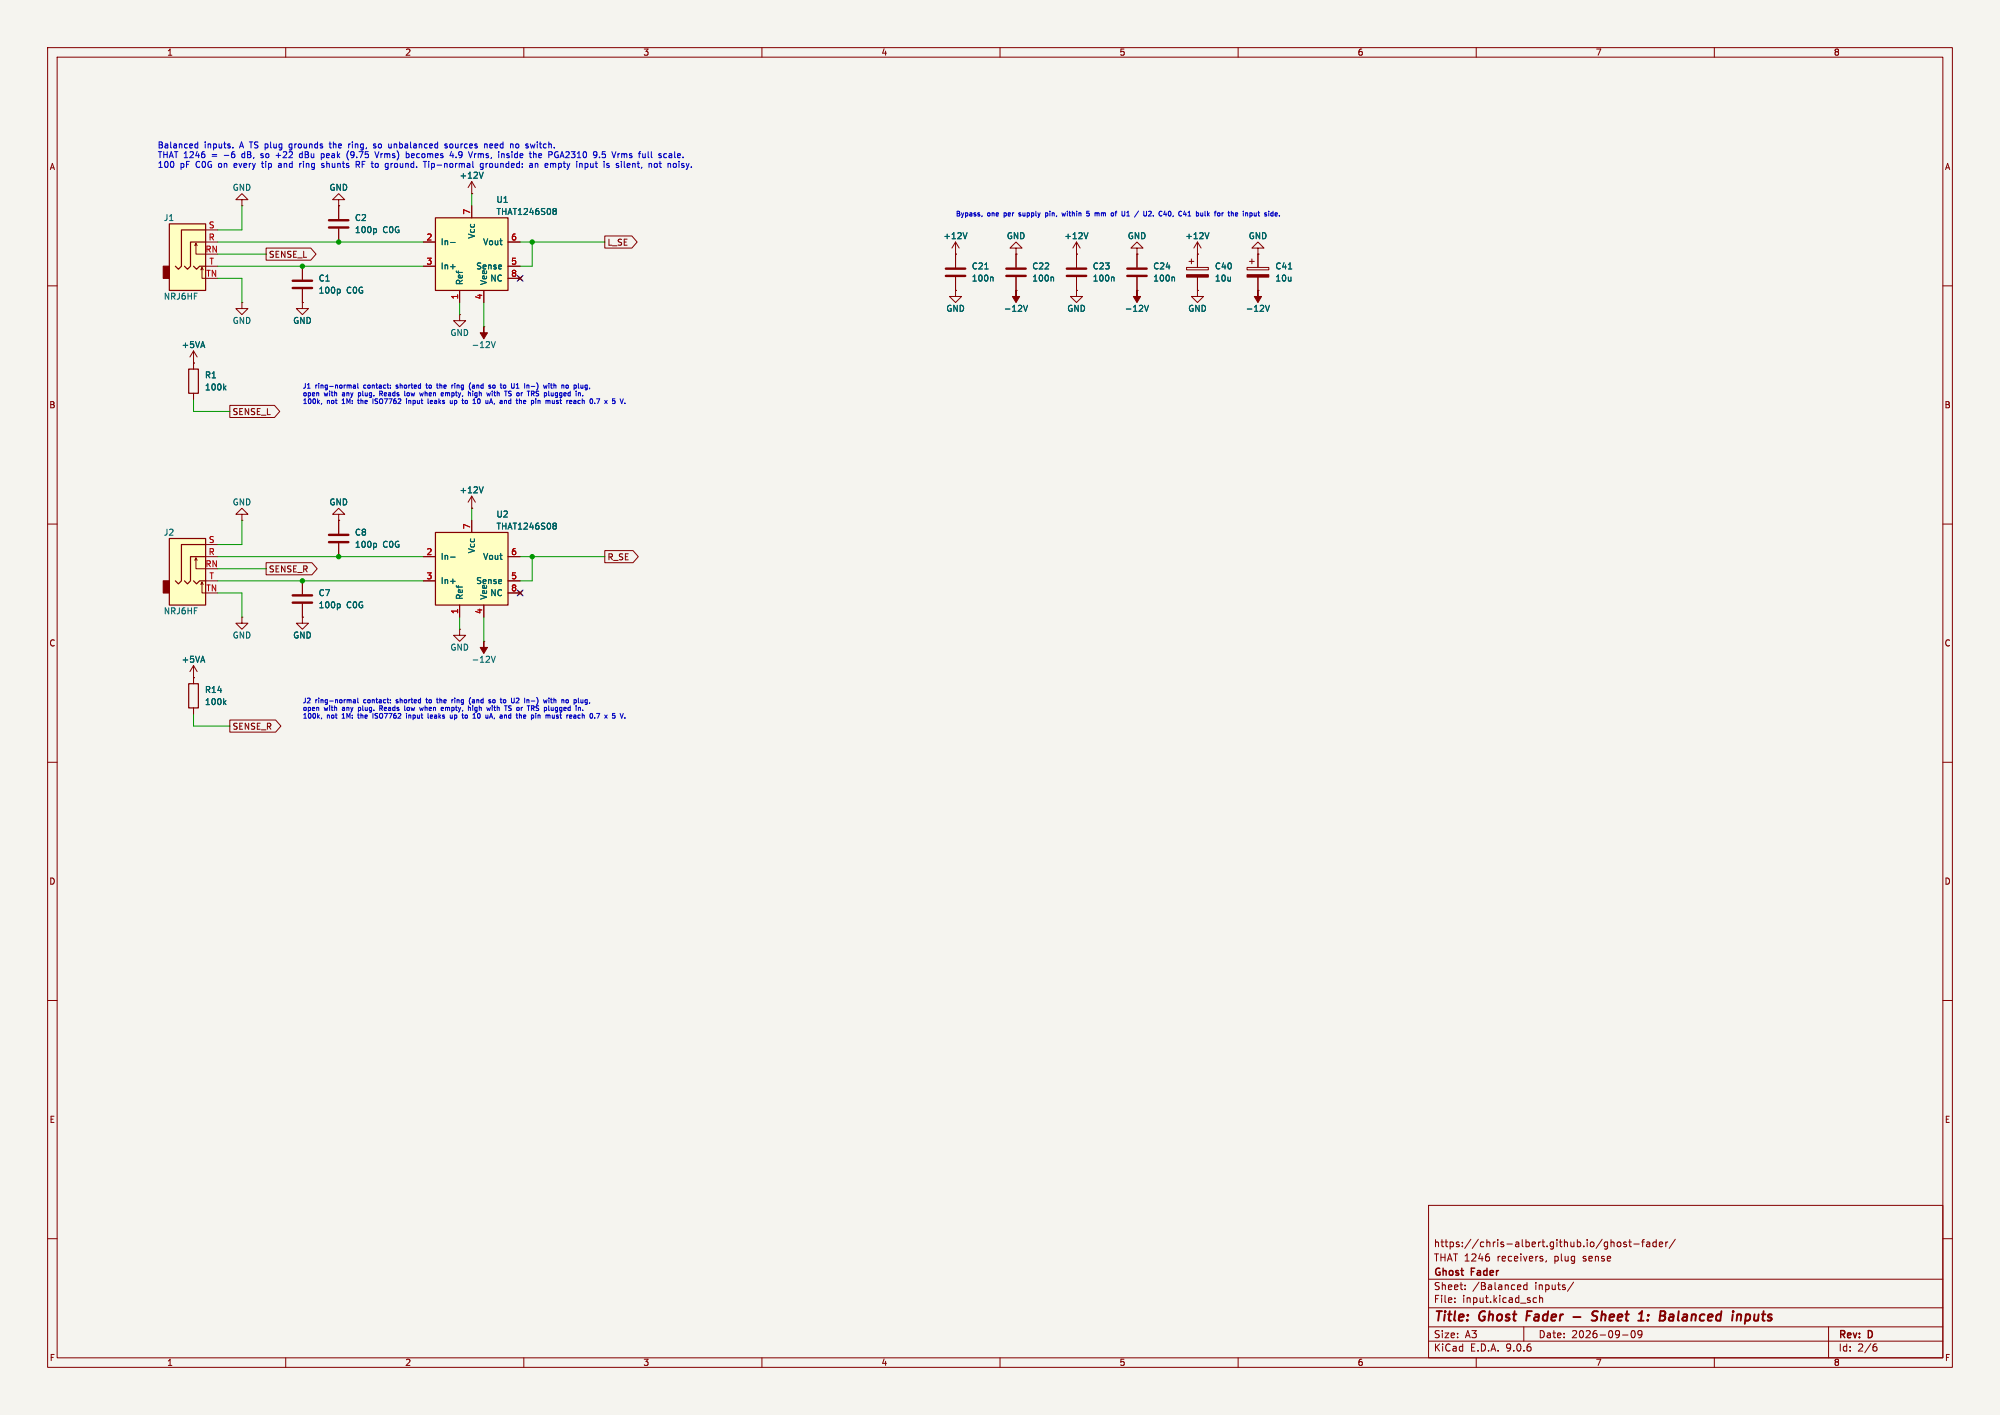
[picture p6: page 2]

4 Vout 6 Sense 5 NC 8 U1 THAT1246S08 GND GND

4 Vout 6 Sense 5 NC 8 GND

4 Vout 6 Sense 5 NC 8 U2 THAT1246S08 GND

4 Vout 6 Sense 5 NC 8 +12V GND

https://chris-albert.github.io/ghost-fader/

Id: 2/6 Title: Ghost Fader - Sheet 1: Balanced inputs

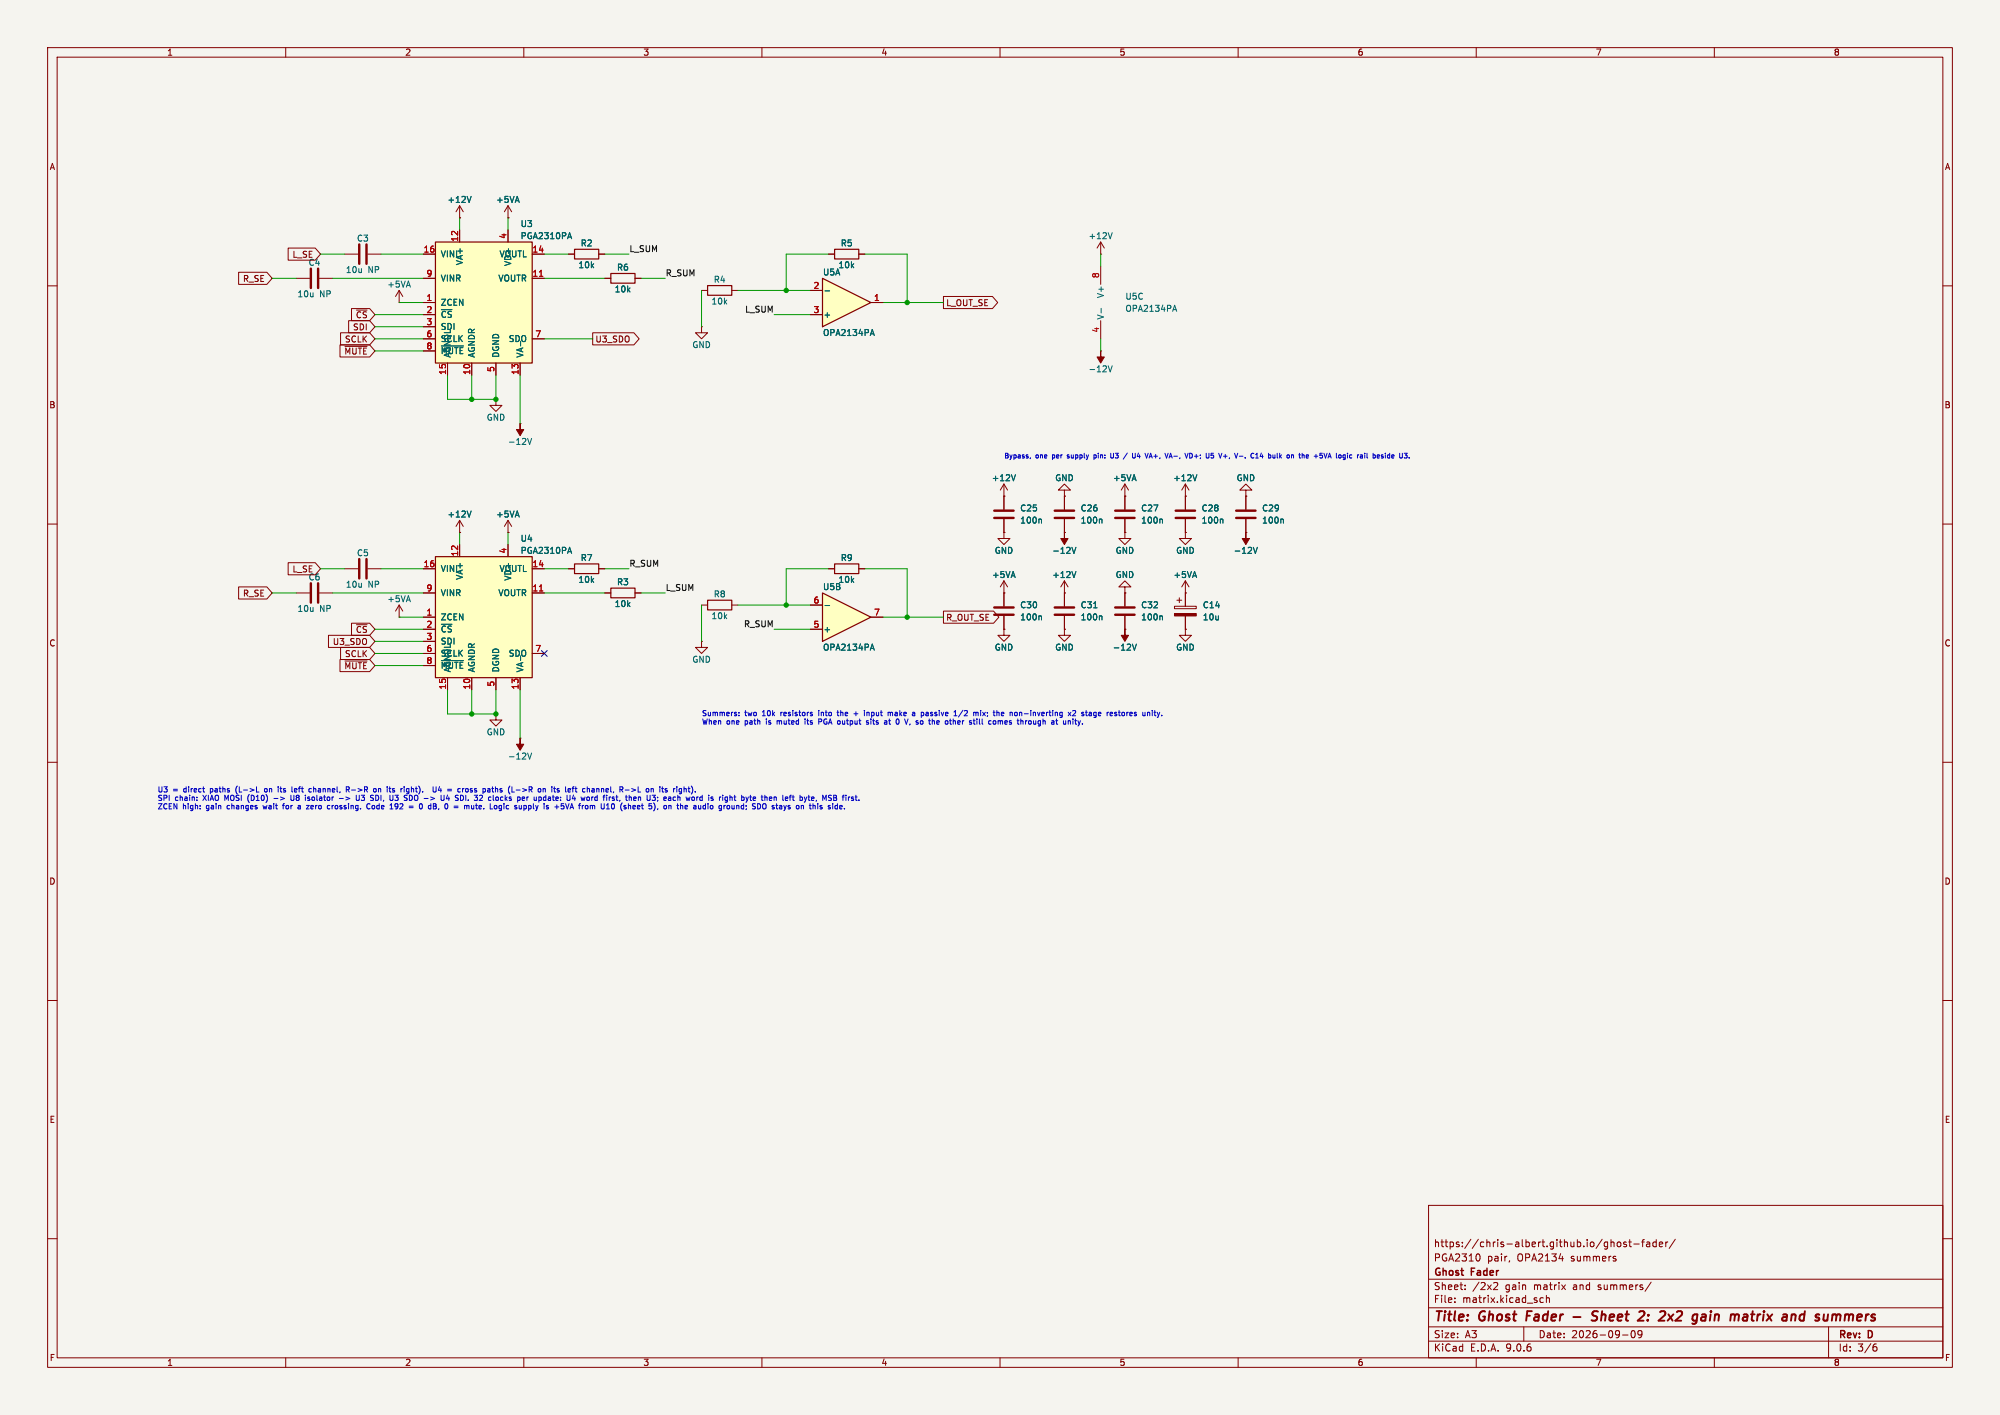
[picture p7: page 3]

4 VA- 13 VOUTL 14 VOUTR 11 SDO 7 +5VA U5A OPA2134PA

4 VA- 13 VOUTL 14 VOUTR 11 SDO 7 U3PGA2310PA

4 VA- 13 VOUTL 14 VOUTR 11 SDO 7 U4PGA2310PA R4

4 VA- 13 VOUTL 14 VOUTR 11 SDO 7 R7

Id: 3/6 Title: Ghost Fader - Sheet 2: 2x2 gain matrix and summers

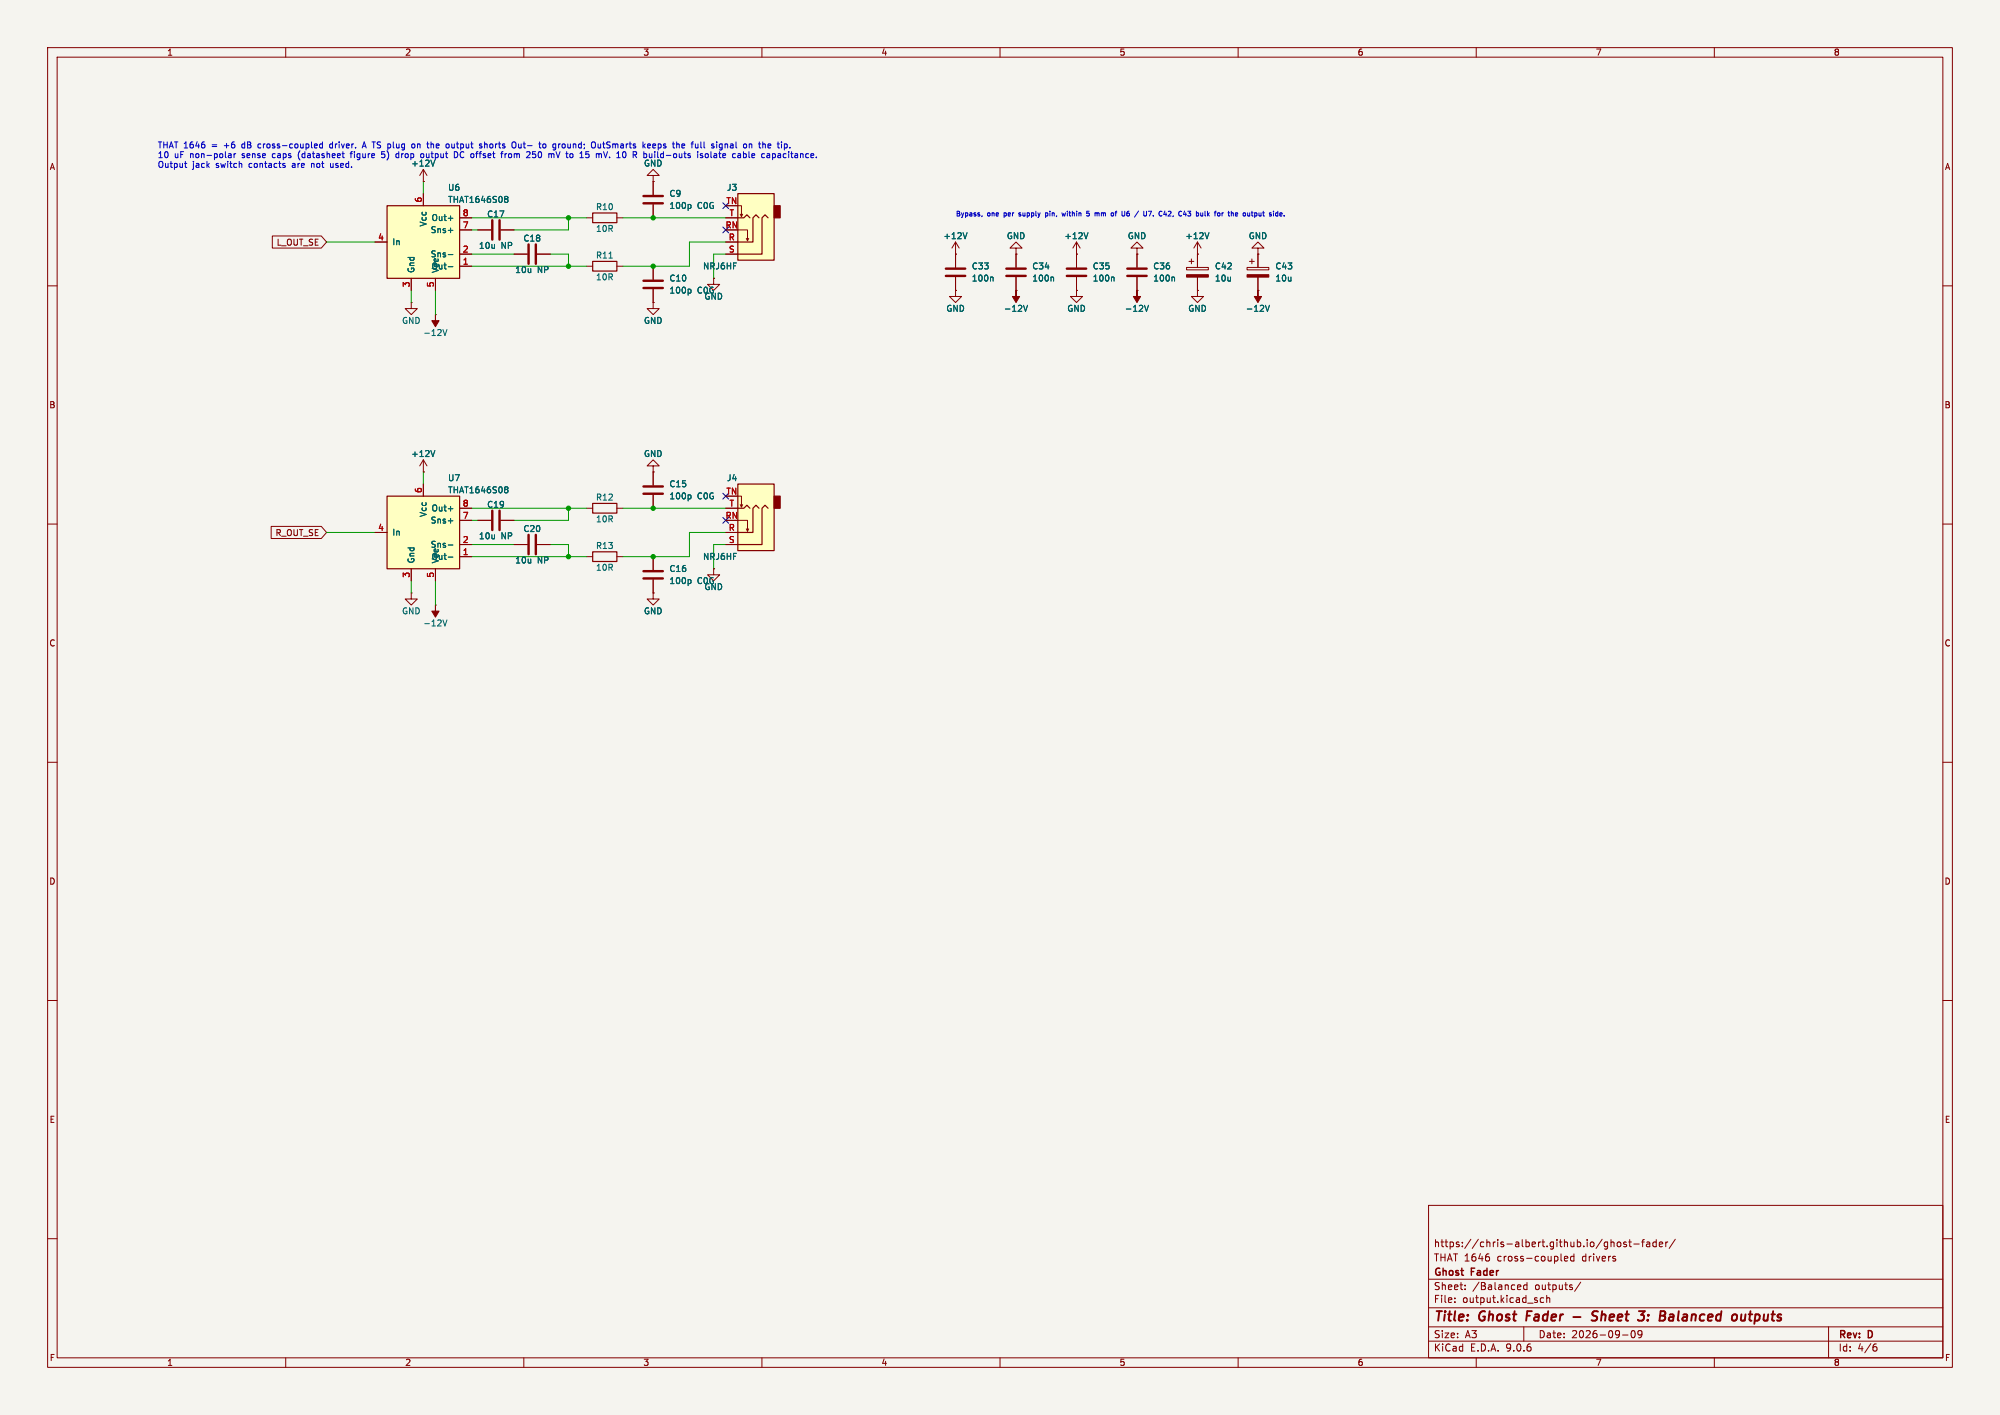
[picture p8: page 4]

5 Out+ 8 Sns+ 7 Sns- 2 Out- 1 U7 THAT1646S08 +12V

5 Out+ 8 Sns+ 7 Sns- 2 Out- 1 U6 THAT1646S08 R10

5 Out+ 8 Sns+ 7 Sns- 2 Out- 1

5 Out+ 8 Sns+ 7 Sns- 2 Out- 1 C19

Id: 4/6 Title: Ghost Fader - Sheet 3: Balanced outputs

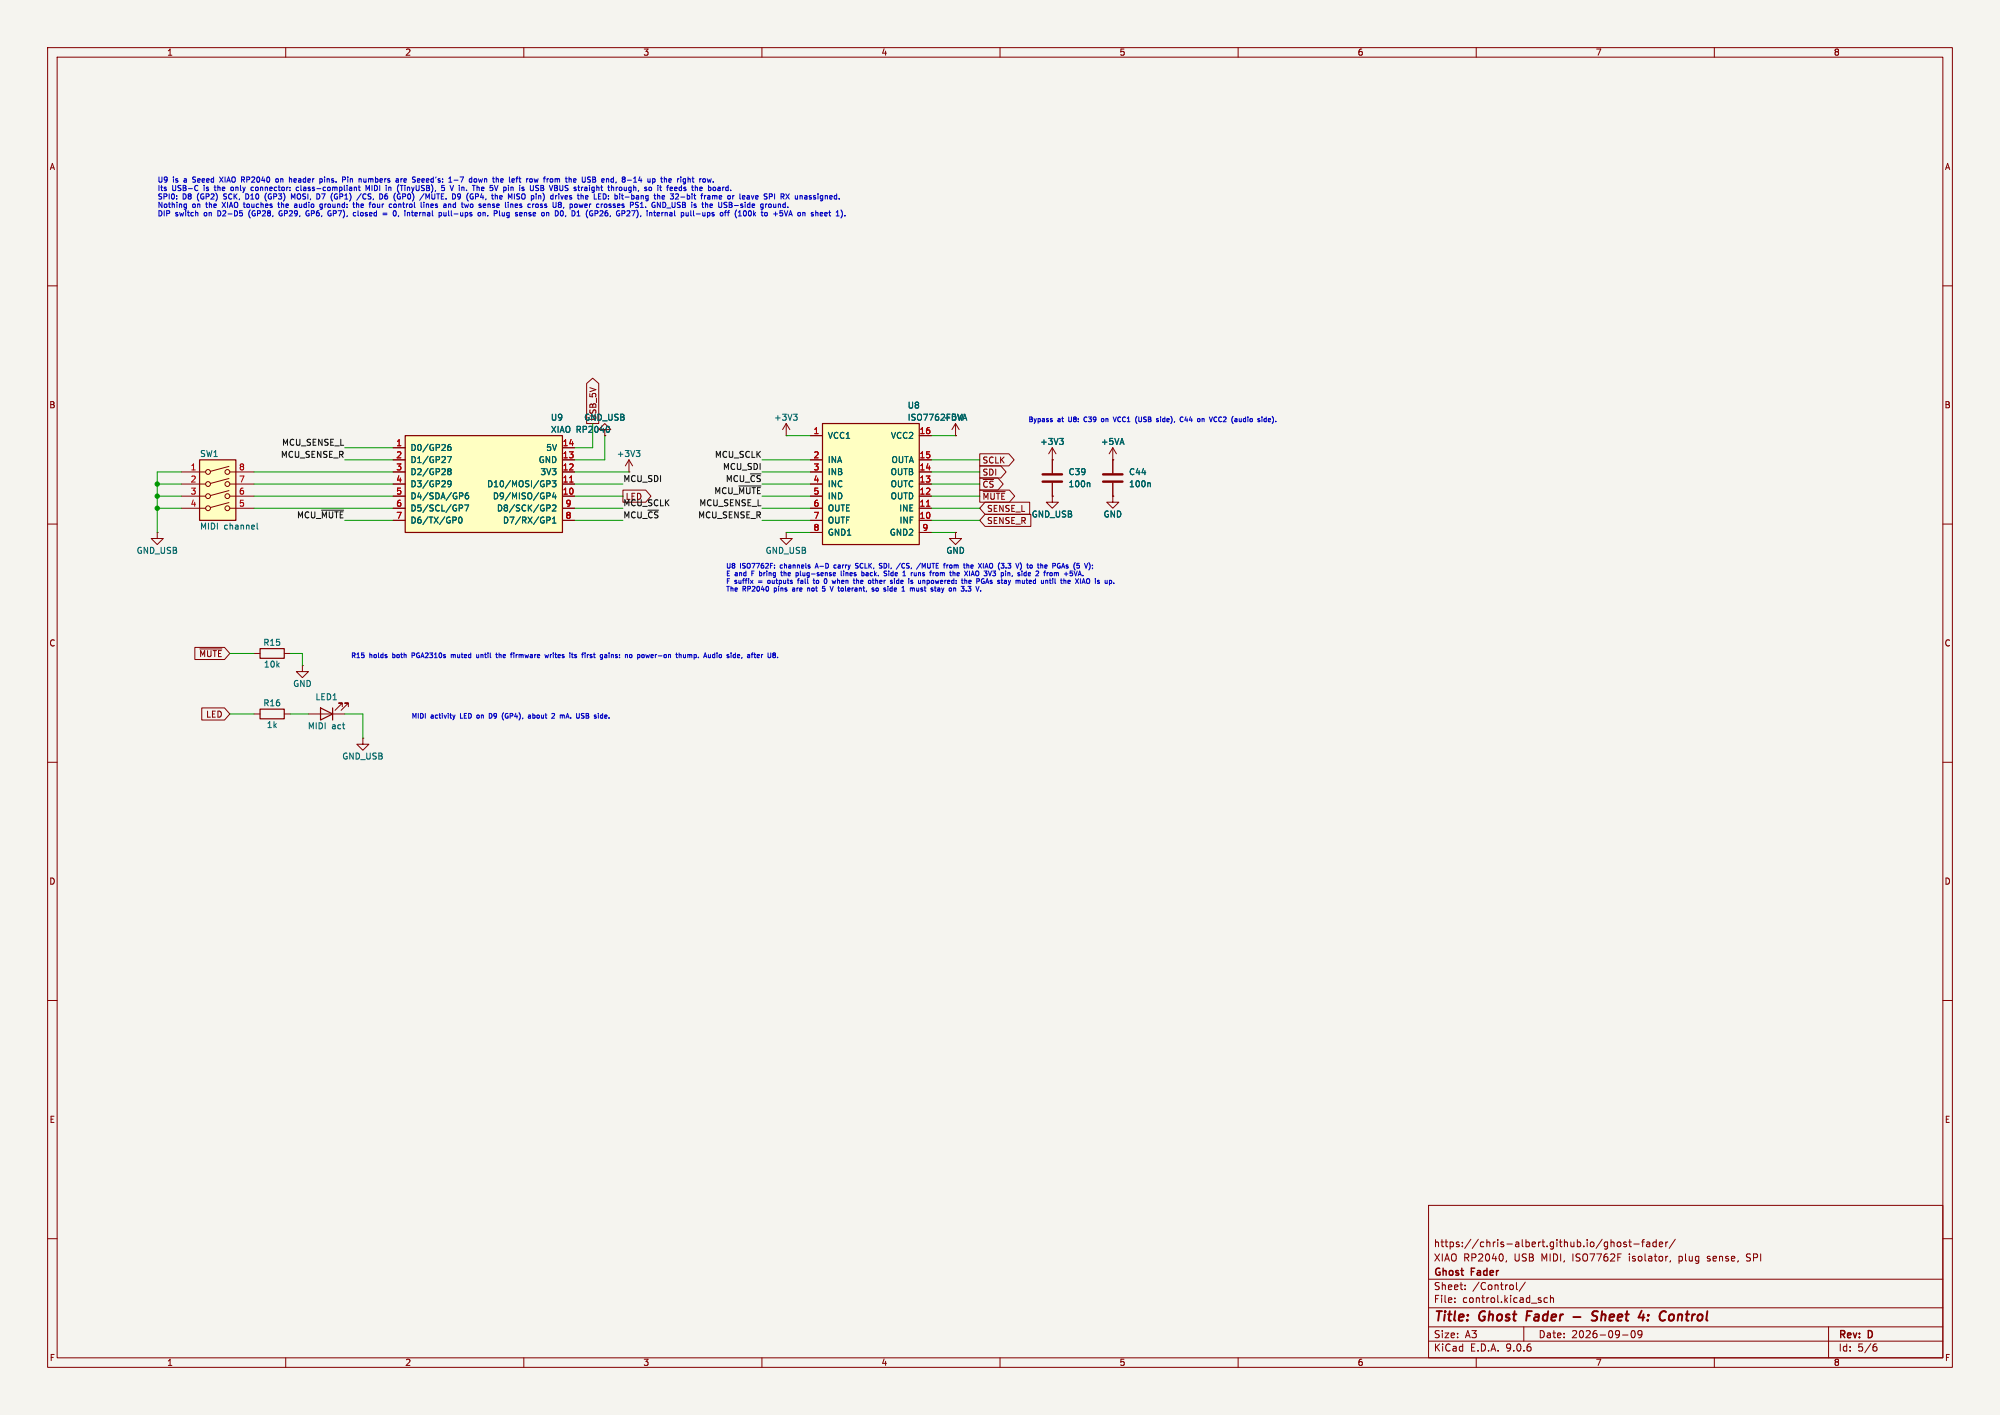
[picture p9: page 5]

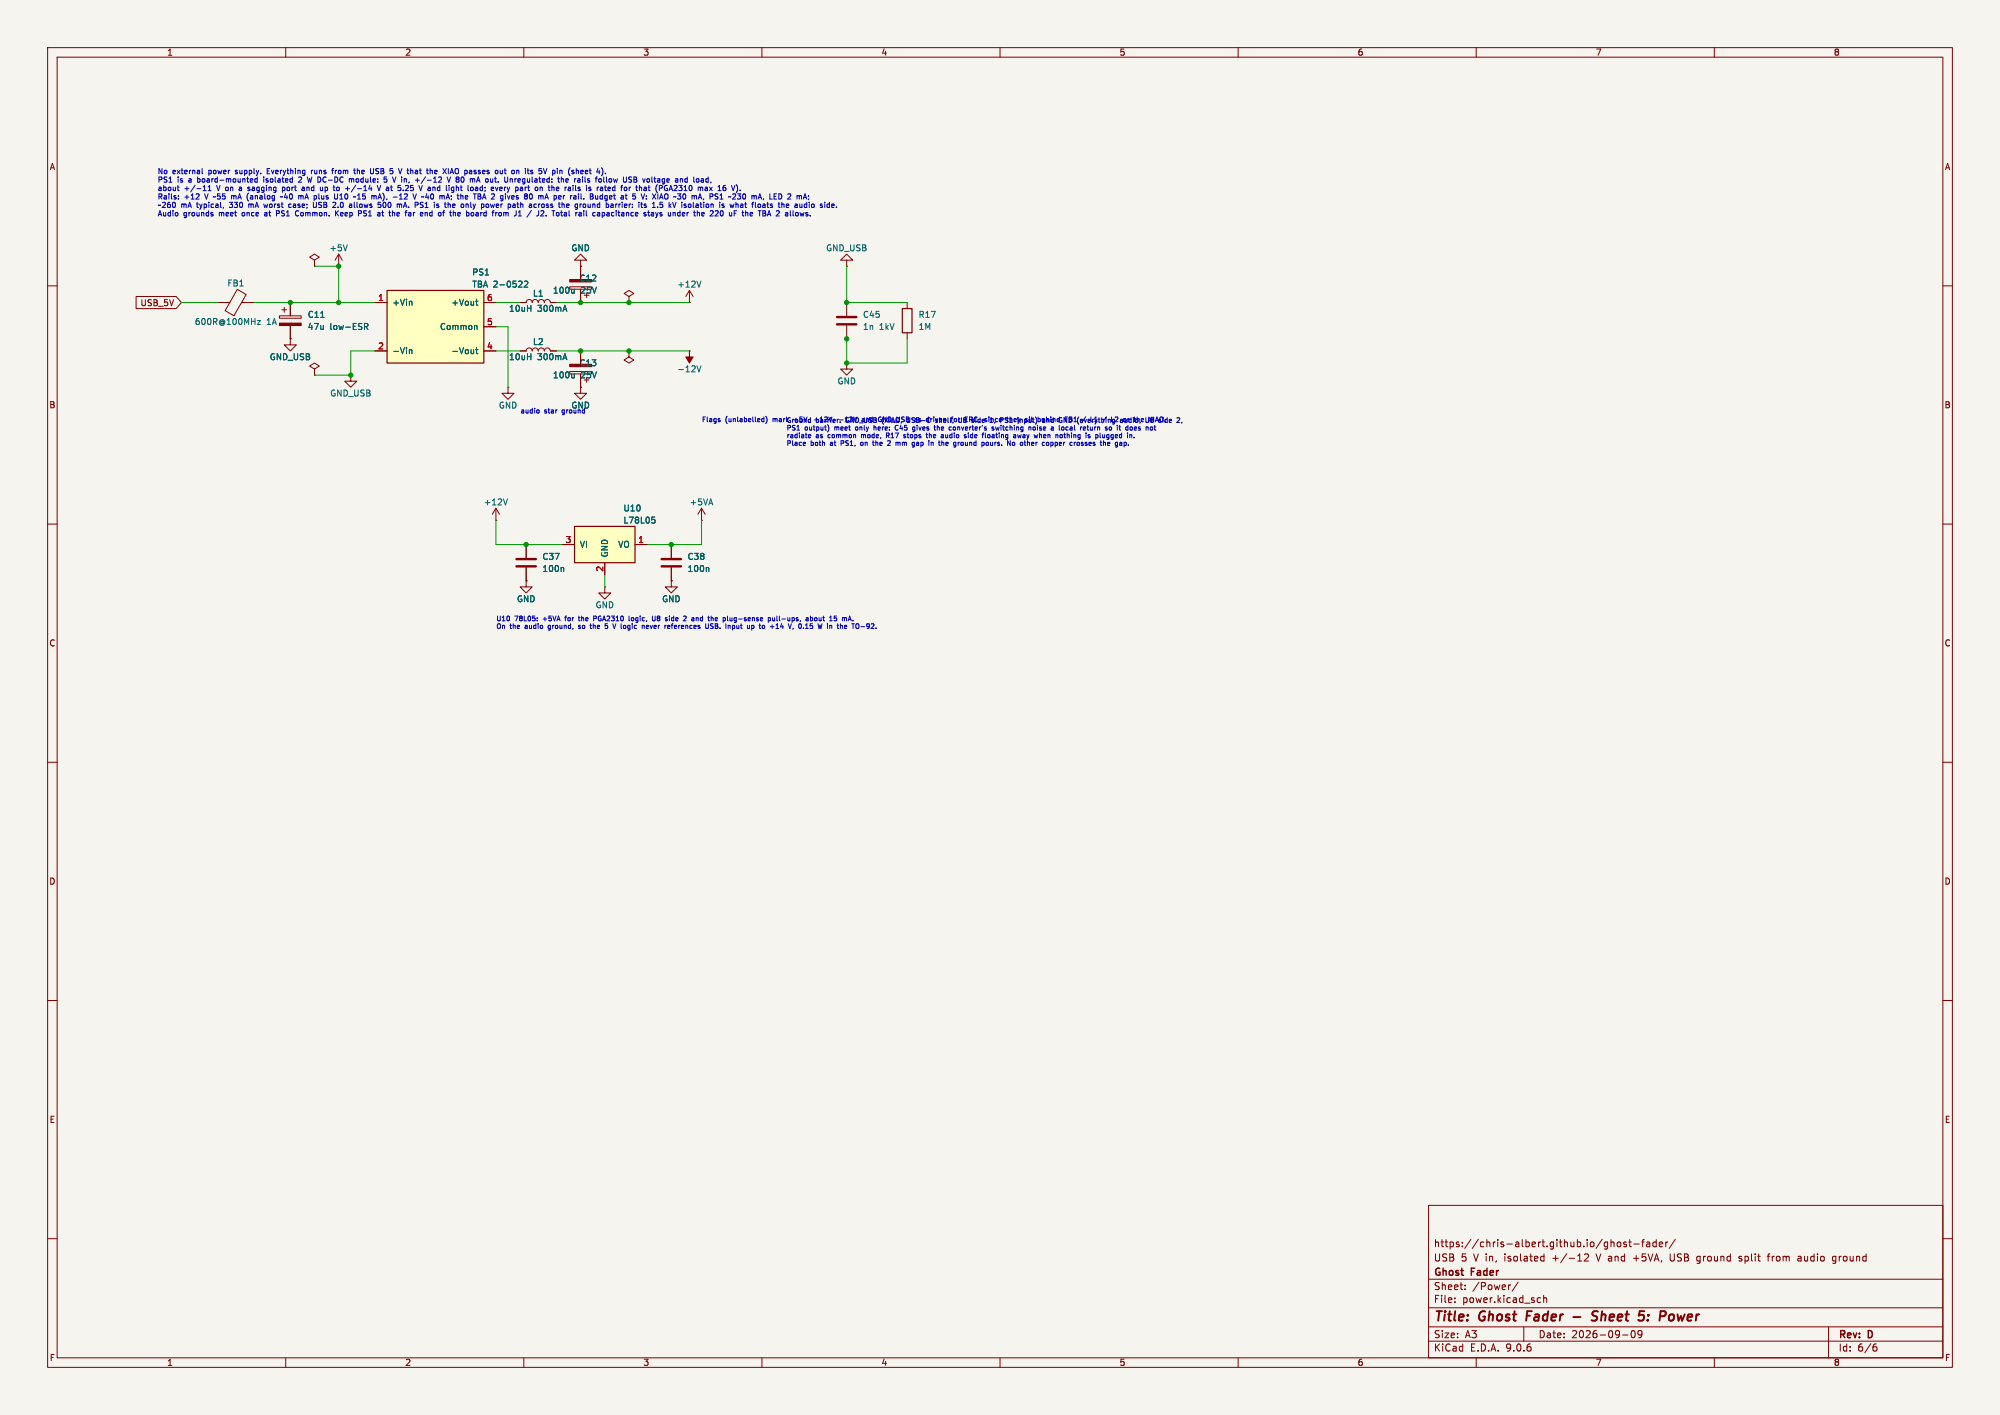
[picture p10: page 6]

https://chris-albert.github.io/ghost-fader/

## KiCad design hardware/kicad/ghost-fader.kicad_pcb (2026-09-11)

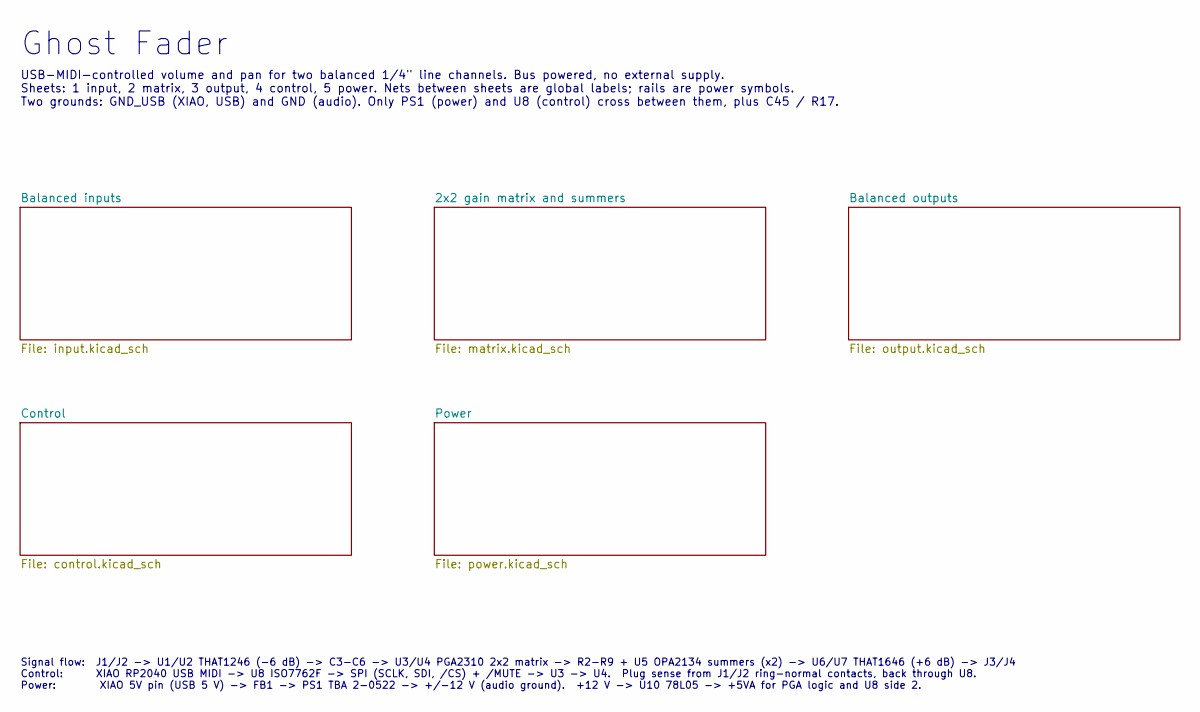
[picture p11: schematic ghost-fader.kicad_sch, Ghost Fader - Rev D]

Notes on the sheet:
Ghost Fader
USB-MIDI-controlled volume and pan for two balanced 1/4" line channels. Bus powered, no external supply. Sheets: 1 input, 2 matrix, 3 output, 4 control, 5 power. Nets between sheets are global labels; rails are power symbols. Two grounds: GND_USB (XIAO, USB) and GND (audio). Only PS1 (power) and U8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
Signal flow: J1/J2 -> U1/U2 THAT1246 (-6 dB) -> C3-C6 -> U3/U4 PGA2310 2x2 matrix -> R2-R9 + U5 OPA2134 summers (x2) -> U6/U7 THAT1646 (+6 dB) -> J3/J4 Control: XIAO RP2040 USB MIDI -> U8 ISO7762F -> SPI (SCLK, SDI, /CS) + /MUTE -> U3 -> U4. Plug sense from J1/J2 ring-normal contacts, back through 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

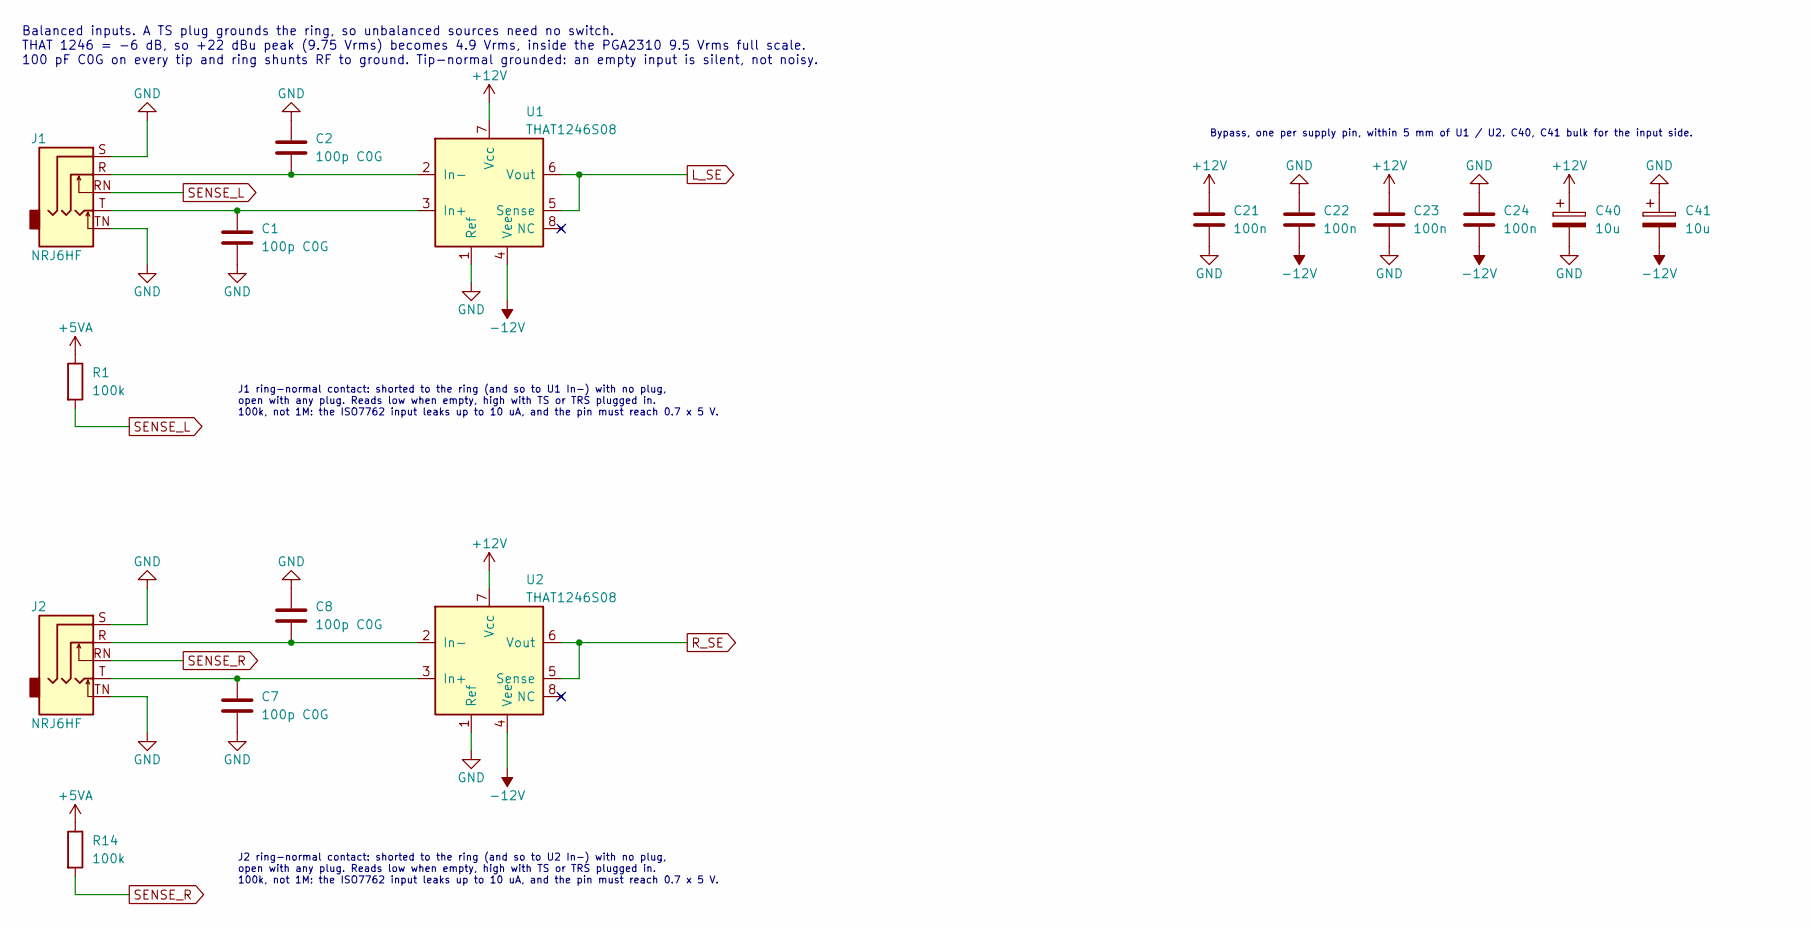
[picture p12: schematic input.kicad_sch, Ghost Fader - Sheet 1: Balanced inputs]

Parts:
C1, C2, C7, C8: 100p C0G; C_Disc_D5.0mm_W2.5mm_P5.00mm
C21, C22, C23, C24: 100n; C_Disc_D5.0mm_W2.5mm_P5.00mm
C40, C41: 10u; CP_Radial_D6.3mm_P2.50mm
J1, J2: NRJ6HF; Jack_6.35mm_Neutrik_NRJ6HF_Horizontal
R1, R14: 100k; R_Axial_DIN0207_L6.3mm_D2.5mm_P10.16mm_Horizontal
U1, U2: THAT1246S08; SOIC-8_3.9x4.9mm_P1.27mm

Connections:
+5VA: R1.1, R14.1; also elsewhere on the board
+12V: C21.1, C23.1, C40.1, U1.7 (Vcc), U2.7 (Vcc); also elsewhere on the board
-12V: C22.2, C24.2, C41.2, U1.4 (Vee), U2.4 (Vee); also elsewhere on the board
GND: C1.2, C2.1, C7.2, C8.1, C21.2, C22.1, C23.2, C24.1, C40.2, C41.1, J1.S, J1.TN, J2.S, J2.TN, U1.1 (Ref), U2.1 (Ref); also elsewhere on the board
L_SE: U1.5 (Sense), U1.6 (Vout); also elsewhere on the board
unnamed: C1.1, J1.T, U1.3 (In+)
unnamed: C2.2, J1.R, U1.2 (In-)
unnamed: C7.1, J2.T, U2.3 (In+)
unnamed: C8.2, J2.R, U2.2 (In-)
R_SE: U2.5 (Sense), U2.6 (Vout); also elsewhere on the board
SENSE_L: J1.RN, R1.2; also elsewhere on the board
SENSE_R: J2.RN, R14.2; also elsewhere on the board

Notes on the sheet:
J1 ring-normal contact: shorted to the ring (and so to U1 In-) with no plug, open with any plug. Reads low when empty, high with TS or TRS plugged in. 100k, not 1M: the ISO7762 input leaks up to 10 uA, and the pin must reach 0.7 x 5 V.
J2 ring-normal contact: shorted to the ring (and so to U2 In-) with no plug, open with any plug. Reads low when empty, high with TS or TRS plugged in. 100k, not 1M: the ISO7762 input leaks up to 10 uA, and the pin must reach 0.7 x 5 V.
Balanced inputs. A TS plug grounds the ring, so unbalanced sources need no switch. THAT 1246 = -6 dB, so +22 dBu peak (9.75 Vrms) becomes 4.9 Vrms, inside the PGA2310 9.5 Vrms full scale. 100 pF C0G on every tip and ring shunts RF to ground. Tip-normal grounded: an empty input is silent, not noisy.
Bypass, one per supply pin, within 5 mm of U1 / U2. C40, C41 bulk for the input side.

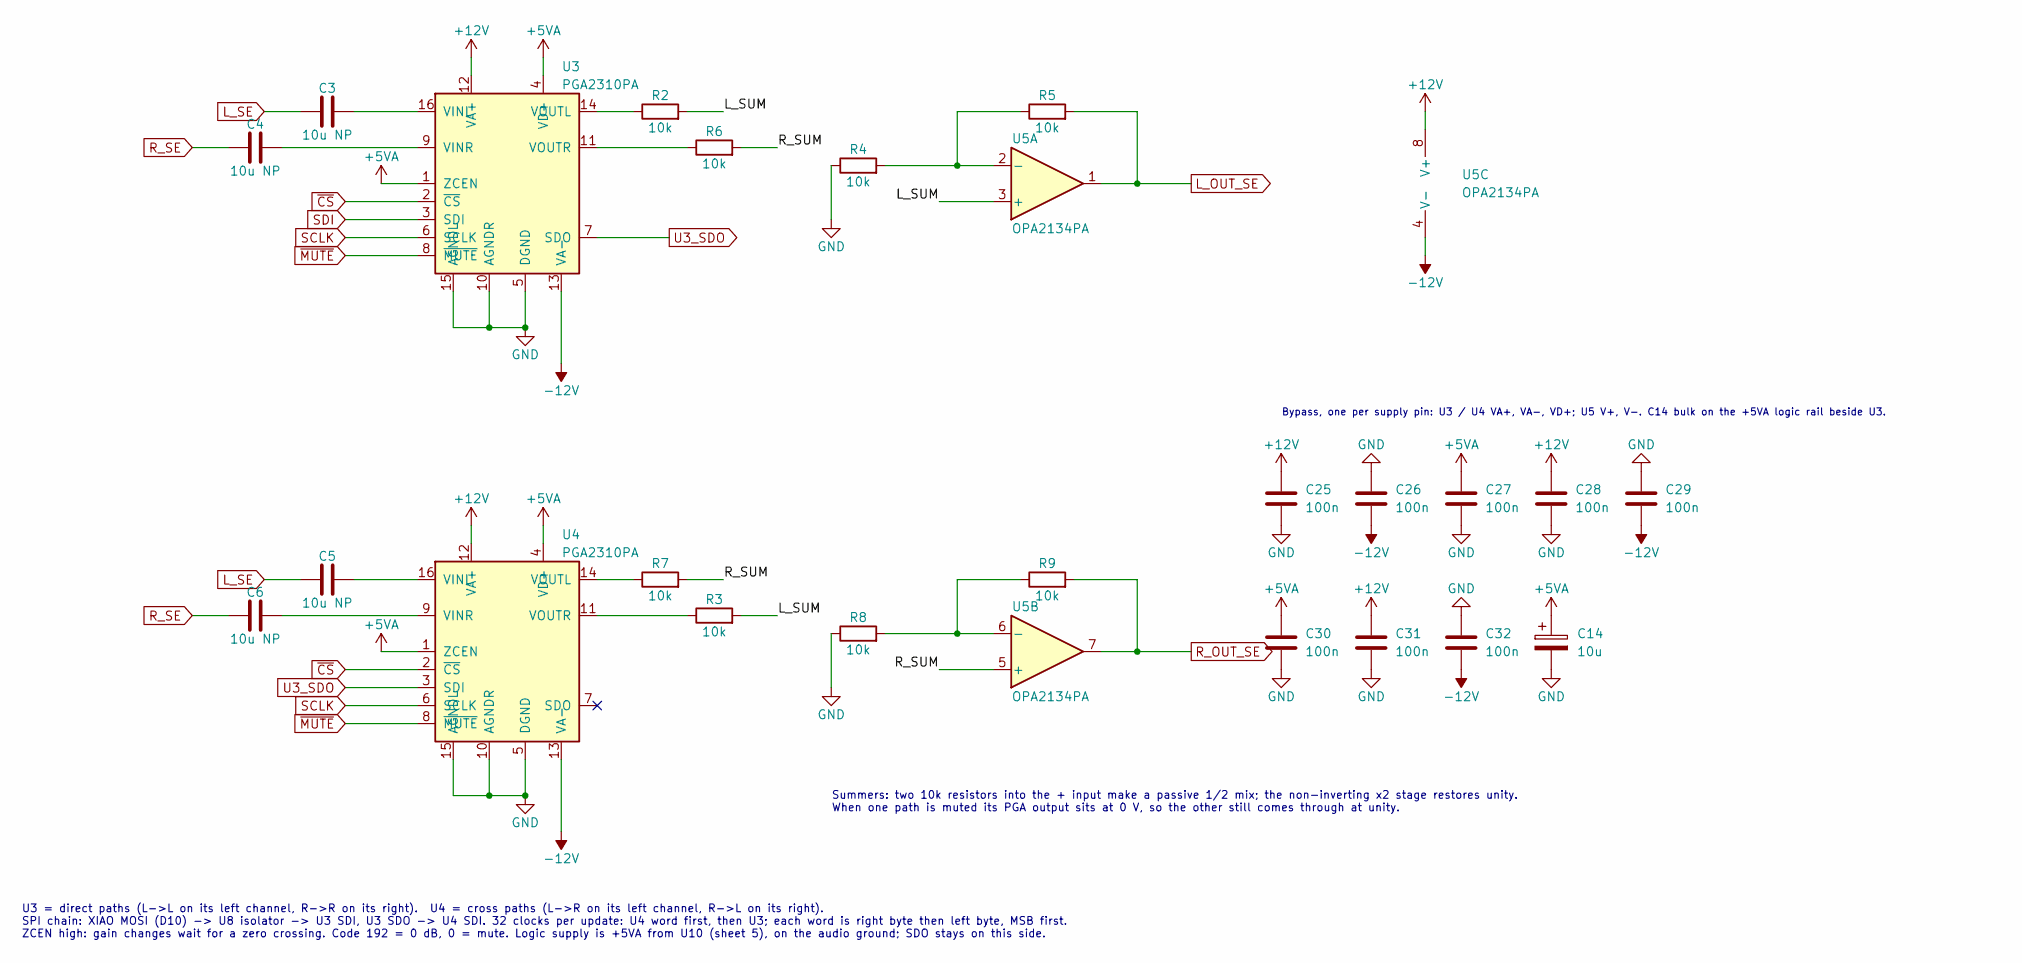
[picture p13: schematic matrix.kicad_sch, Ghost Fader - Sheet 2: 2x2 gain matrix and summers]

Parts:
C3, C4, C5, C6: 10u NP; CP_Radial_D5.0mm_P2.50mm
C14: 10u; CP_Radial_D6.3mm_P2.50mm
C25, C26, C27, C28, C29, C30, C31, C32: 100n; C_Disc_D5.0mm_W2.5mm_P5.00mm
R2, R3, R4, R5, R6, R7, R8, R9: 10k; R_Axial_DIN0207_L6.3mm_D2.5mm_P10.16mm_Horizontal
U3, U4: PGA2310PA; DIP-16_W7.62mm
U5: OPA2134PA; DIP-8_W7.62mm

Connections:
+5VA: C14.1, C27.1, C30.1, U3.1 (ZCEN), U3.4 (VD+), U4.1 (ZCEN), U4.4 (VD+); also elsewhere on the board
+12V: C25.1, C28.1, C31.1, U3.12 (VA+), U4.12 (VA+), U5.8 (V+); also elsewhere on the board
-12V: C26.2, C29.2, C32.2, U3.13 (VA-), U4.13 (VA-), U5.4 (V-); also elsewhere on the board
/2x2 gain matrix and summers/L_SUM: R2.2, R3.2, U5.3 (+)
/2x2 gain matrix and summers/R_SUM: R6.2, R7.2, U5.5 (+)
GND: C14.2, C25.2, C26.1, C27.2, C28.2, C29.1, C30.2, C31.2, C32.1, R4.1, R8.1, U3.5 (DGND), U3.10 (AGNDR), U3.15 (AGNDL), U4.5 (DGND), U4.10 (AGNDR), U4.15 (AGNDL); also elsewhere on the board
L_OUT_SE: R5.2, U5.1; also elsewhere on the board
L_SE: C3.1, C5.1; also elsewhere on the board
unnamed: C3.2, U3.16 (VINL)
unnamed: C4.2, U3.9 (VINR)
unnamed: R2.1, U3.14 (VOUTL)
unnamed: R6.1, U3.11 (VOUTR)
unnamed: C5.2, U4.16 (VINL)
unnamed: C6.2, U4.9 (VINR)
unnamed: R7.1, U4.14 (VOUTL)
unnamed: R3.1, U4.11 (VOUTR)
unnamed: R4.2, R5.1, U5.2 (-)
unnamed: R8.2, R9.1, U5.6 (-)
R_OUT_SE: R9.2, U5.7; also elsewhere on the board
R_SE: C4.1, C6.1; also elsewhere on the board
SCLK: U3.6 (SCLK), U4.6 (SCLK); also elsewhere on the board
SDI: U3.3 (SDI); also elsewhere on the board
U3_SDO: U3.7 (SDO), U4.3 (SDI)
~CS: U3.2 (~CS), U4.2 (~CS); also elsewhere on the board
~MUTE: U3.8 (~MUTE), U4.8 (~MUTE); also elsewhere on the board

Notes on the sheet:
U3 = direct paths (L->L on its left channel, R->R on its right). U4 = cross paths (L->R on its left channel, R->L on its right). SPI chain: XIAO MOSI (D10) -> U8 isolator -> U3 SDI, U3 SDO -> U4 SDI. 32 clocks per update: U4 word first, then U3; each word is right byte then left byte, MSB first. ZC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
Summers: two 10k resistors into the + input make a passive 1/2 mix; the non-inverting x2 stage restores unity. When one path is muted its PGA output sits at 0 V, so the other still comes through at unity.
Bypass, one per supply pin: U3 / U4 VA+, VA-, VD+; U5 V+, V-. C14 bulk on the +5VA logic rail beside U3.

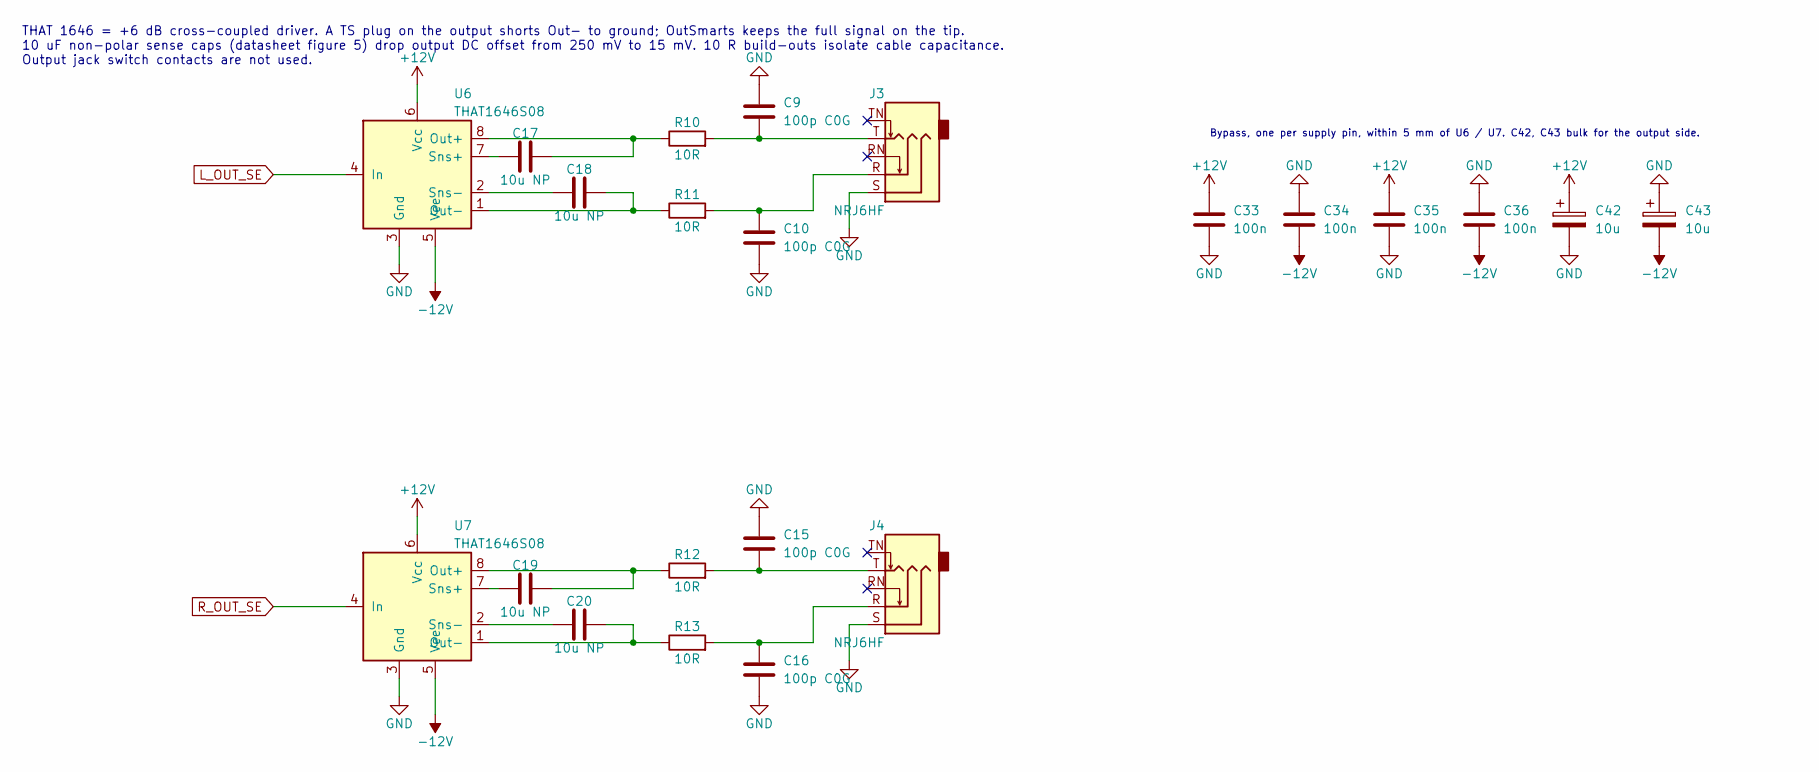
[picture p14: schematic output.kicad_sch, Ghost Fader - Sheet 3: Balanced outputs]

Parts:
C9, C10, C15, C16: 100p C0G; C_Disc_D5.0mm_W2.5mm_P5.00mm
C17, C18, C19, C20: 10u NP; CP_Radial_D5.0mm_P2.50mm
C33, C34, C35, C36: 100n; C_Disc_D5.0mm_W2.5mm_P5.00mm
C42, C43: 10u; CP_Radial_D6.3mm_P2.50mm
J3, J4: NRJ6HF; Jack_6.35mm_Neutrik_NRJ6HF_Horizontal
R10, R11, R12, R13: 10R; R_Axial_DIN0207_L6.3mm_D2.5mm_P10.16mm_Horizontal
U6, U7: THAT1646S08; SOIC-8_3.9x4.9mm_P1.27mm

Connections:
+12V: C33.1, C35.1, C42.1, U6.6 (Vcc), U7.6 (Vcc); also elsewhere on the board
-12V: C34.2, C36.2, C43.2, U6.5 (Vee), U7.5 (Vee); also elsewhere on the board
GND: C9.1, C10.2, C15.1, C16.2, C33.2, C34.1, C35.2, C36.1, C42.2, C43.1, J3.S, J4.S, U6.3 (Gnd), U7.3 (Gnd); also elsewhere on the board
L_OUT_SE: U6.4 (In); also elsewhere on the board
unnamed: C9.2, J3.T, R10.2
unnamed: C10.1, J3.R, R11.2
unnamed: C15.2, J4.T, R12.2
unnamed: C16.1, J4.R, R13.2
unnamed: C17.2, R10.1, U6.8 (Out+)
unnamed: C18.2, R11.1, U6.1 (Out-)
unnamed: C17.1, U6.7 (Sns+)
unnamed: C18.1, U6.2 (Sns-)
unnamed: C19.2, R12.1, U7.8 (Out+)
unnamed: C20.2, R13.1, U7.1 (Out-)
unnamed: C19.1, U7.7 (Sns+)
unnamed: C20.1, U7.2 (Sns-)
R_OUT_SE: U7.4 (In); also elsewhere on the board

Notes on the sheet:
THAT 1646 = +6 dB cross-coupled driver. A TS plug on the output shorts Out- to ground; OutSmarts keeps the full signal on the tip. 10 uF non-polar sense caps (datasheet figure 5) drop output DC offset from 250 mV to 15 mV. 10 R build-outs isolate cable capacitance. Output jack switch contacts are n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
Bypass, one per supply pin, within 5 mm of U6 / U7. C42, C43 bulk for the output side.

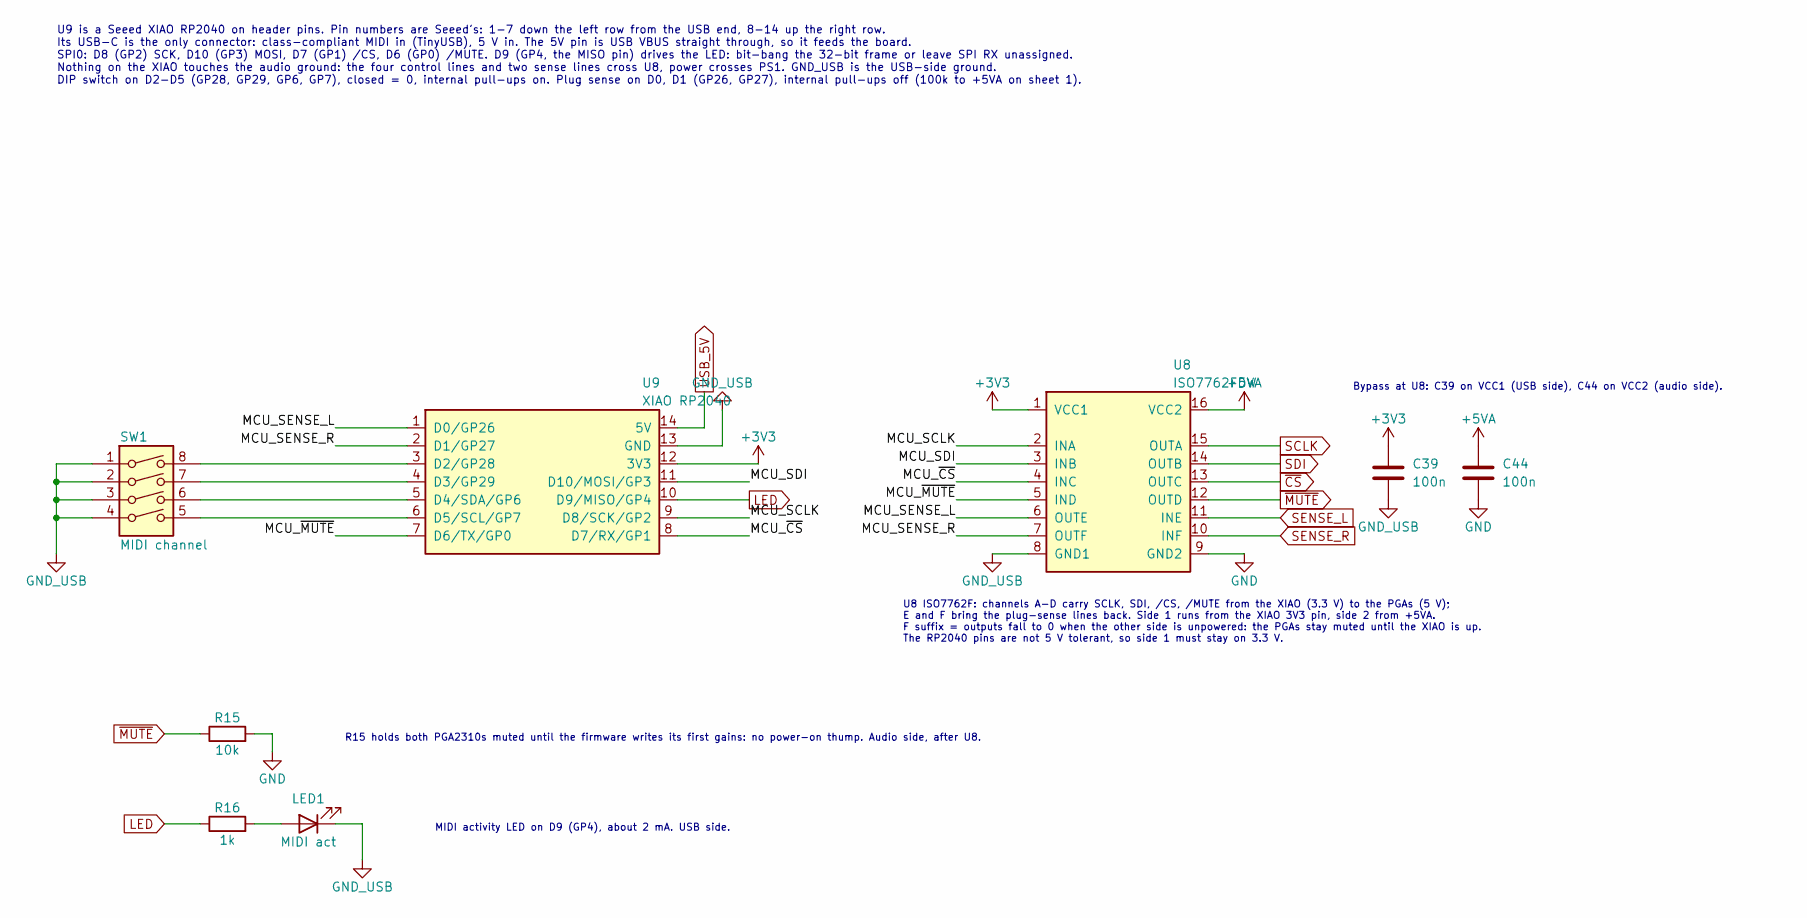
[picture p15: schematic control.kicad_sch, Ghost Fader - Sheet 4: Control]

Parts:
C39, C44: 100n; C_Disc_D5.0mm_W2.5mm_P5.00mm
LED1: MIDI act; LED_D3.0mm
R15: 10k; R_Axial_DIN0207_L6.3mm_D2.5mm_P10.16mm_Horizontal
R16: 1k; R_Axial_DIN0207_L6.3mm_D2.5mm_P10.16mm_Horizontal
SW1: MIDI channel; SW_DIP_SPSTx04_Slide_6.7x11.72mm_W7.62mm_P2.54mm_LowProfile
U8: ISO7762FDW; SOIC-16W_7.5x10.3mm_P1.27mm
U9: XIAO RP2040; XIAO_RP2040_THT

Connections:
+3V3: C39.1, U8.1 (VCC1), U9.12 (3V3)
+5VA: C44.1, U8.16 (VCC2); also elsewhere on the board
/Control/MCU_SCLK: U8.2 (INA), U9.9 (D8/SCK/GP2)
/Control/MCU_SDI: U8.3 (INB), U9.11 (D10/MOSI/GP3)
/Control/MCU_SENSE_L: U8.6 (OUTE), U9.1 (D0/GP26)
/Control/MCU_SENSE_R: U8.7 (OUTF), U9.2 (D1/GP27)
/Control/MCU_~CS: U8.4 (INC), U9.8 (D7/RX/GP1)
/Control/MCU_~MUTE: U8.5 (IND), U9.7 (D6/TX/GP0)
GND: C44.2, R15.2, U8.9 (GND2); also elsewhere on the board
GND_USB: C39.2, LED1.1 (K), SW1.1, SW1.2, SW1.3, SW1.4, U8.8 (GND1), U9.13 (GND); also elsewhere on the board
LED: R16.1, U9.10 (D9/MISO/GP4)
unnamed: LED1.2 (A), R16.2
unnamed: SW1.8, U9.3 (D2/GP28)
unnamed: SW1.7, U9.4 (D3/GP29)
unnamed: SW1.6, U9.5 (D4/SDA/GP6)
unnamed: SW1.5, U9.6 (D5/SCL/GP7)
SCLK: U8.15 (OUTA); also elsewhere on the board
SDI: U8.14 (OUTB); also elsewhere on the board
SENSE_L: U8.11 (INE); also elsewhere on the board
SENSE_R: U8.10 (INF); also elsewhere on the board
USB_5V: U9.14 (5V); also elsewhere on the board
~CS: U8.13 (OUTC); also elsewhere on the board
~MUTE: R15.1, U8.12 (OUTD); also elsewhere on the board

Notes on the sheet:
U8 ISO7762F: channels A-D carry SCLK, SDI, /CS, /MUTE from the XIAO (3.3 V) to the PGAs (5 V); E and F bring the plug-sense lines back. Side 1 runs from the XIAO 3V3 pin, side 2 from +5VA. F suffix = outputs fall to 0 when the other side is unpowered: the PGAs stay muted until the XIAO is up. The R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
Bypass at U8: C39 on VCC1 (USB side), C44 on VCC2 (audio side).
MIDI activity LED on D9 (GP4), about 2 mA. USB side.
R15 holds both PGA2310s muted until the firmware writes its first gains: no power-on thump. Audio side, after U8.
U9 is a Seeed XIAO RP2040 on header pins. Pin numbers are Seeed's: 1-7 down the left row from the USB end, 8-14 up the right row. Its USB-C is the only connector: class-compliant MIDI in (TinyUSB), 5 V in. The 5V pin is USB VBUS straight through, so it feeds the board. SPI0: D8 (GP2) SCK, D10 (GP3)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

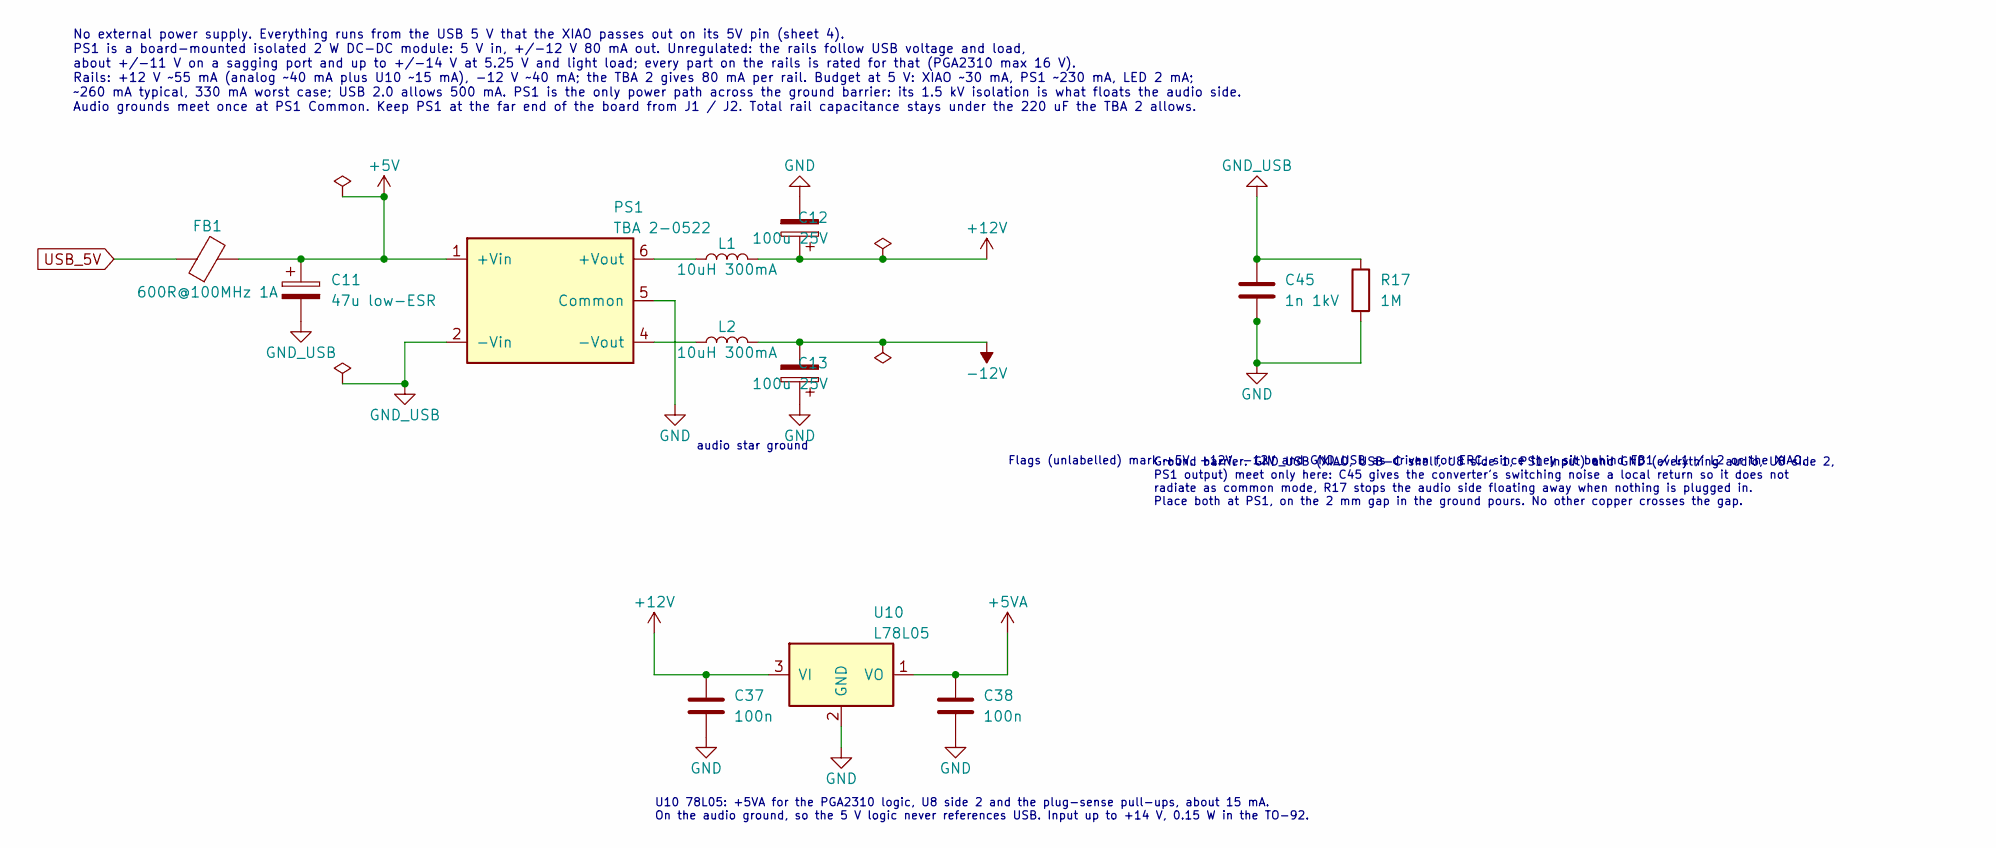
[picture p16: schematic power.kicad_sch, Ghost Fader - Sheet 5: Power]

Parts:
C11: 47u low-ESR; CP_Radial_D6.3mm_P2.50mm
C12, C13: 100u 25V; CP_Radial_D6.3mm_P2.50mm
C37, C38: 100n; C_Disc_D5.0mm_W2.5mm_P5.00mm
C45: 1n 1kV; C_Disc_D5.0mm_W2.5mm_P5.00mm
FB1: 600R@100MHz 1A; L_Axial_L7.0mm_D3.3mm_P10.16mm_Horizontal_Fastron_MICC
L1, L2: 10uH 300mA; L_Axial_L7.0mm_D3.3mm_P10.16mm_Horizontal_Fastron_MICC
PS1: TBA 2-0522; Converter_DCDC_TRACO_TBA2-xxxx_Dual_THT
R17: 1M; R_Axial_DIN0207_L6.3mm_D2.5mm_P10.16mm_Horizontal
U10: L78L05; TO-92_Inline_Wide

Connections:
+5V: C11.1, FB1.2, PS1.1 (+Vin)
+5VA: C38.1, U10.1 (VO); also elsewhere on the board
+12V: C12.1, C37.1, L1.2, U10.3 (VI); also elsewhere on the board
-12V: C13.2, L2.2; also elsewhere on the board
GND: C12.2, C13.1, C37.2, C38.2, C45.2, PS1.5 (Common), R17.2, U10.2 (GND); also elsewhere on the board
GND_USB: C11.2, C45.1, PS1.2 (-Vin), R17.1; also elsewhere on the board
unnamed: L1.1, PS1.6 (+Vout)
unnamed: L2.1, PS1.4 (-Vout)
USB_5V: FB1.1; also elsewhere on the board

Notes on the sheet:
audio star ground
U10 78L05: +5VA for the PGA2310 logic, U8 side 2 and the plug-sense pull-ups, about 15 mA. On the audio ground, so the 5 V logic never references USB. Input up to +14 V, 0.15 W in the TO-92.
Ground barrier. GND_USB (XIAO, USB-C shell, U8 side 1, PS1 input) and GND (everything audio, U8 side 2, PS1 output) meet only here: C45 gives the converter's switching noise a local return so it does not radiate as common mode, R17 stops the audio side floating away when nothing is plugged in. Plac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
No external power supply. Everything runs from the USB 5 V that the XIAO passes out on its 5V pin (sheet 4). PS1 is a board-mounted isolated 2 W DC-DC module: 5 V in, +/-12 V 80 mA out. Unregulated: the rails follow USB voltage and load, about +/-11 V on a sagging port and up to +/-14 V at 5.25 V a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
Flags (unlabelled) mark +5V, +12V, -12V and GND_USB as driven for ERC, since they sit behind FB1 / L1 / L2 or the XIAO.

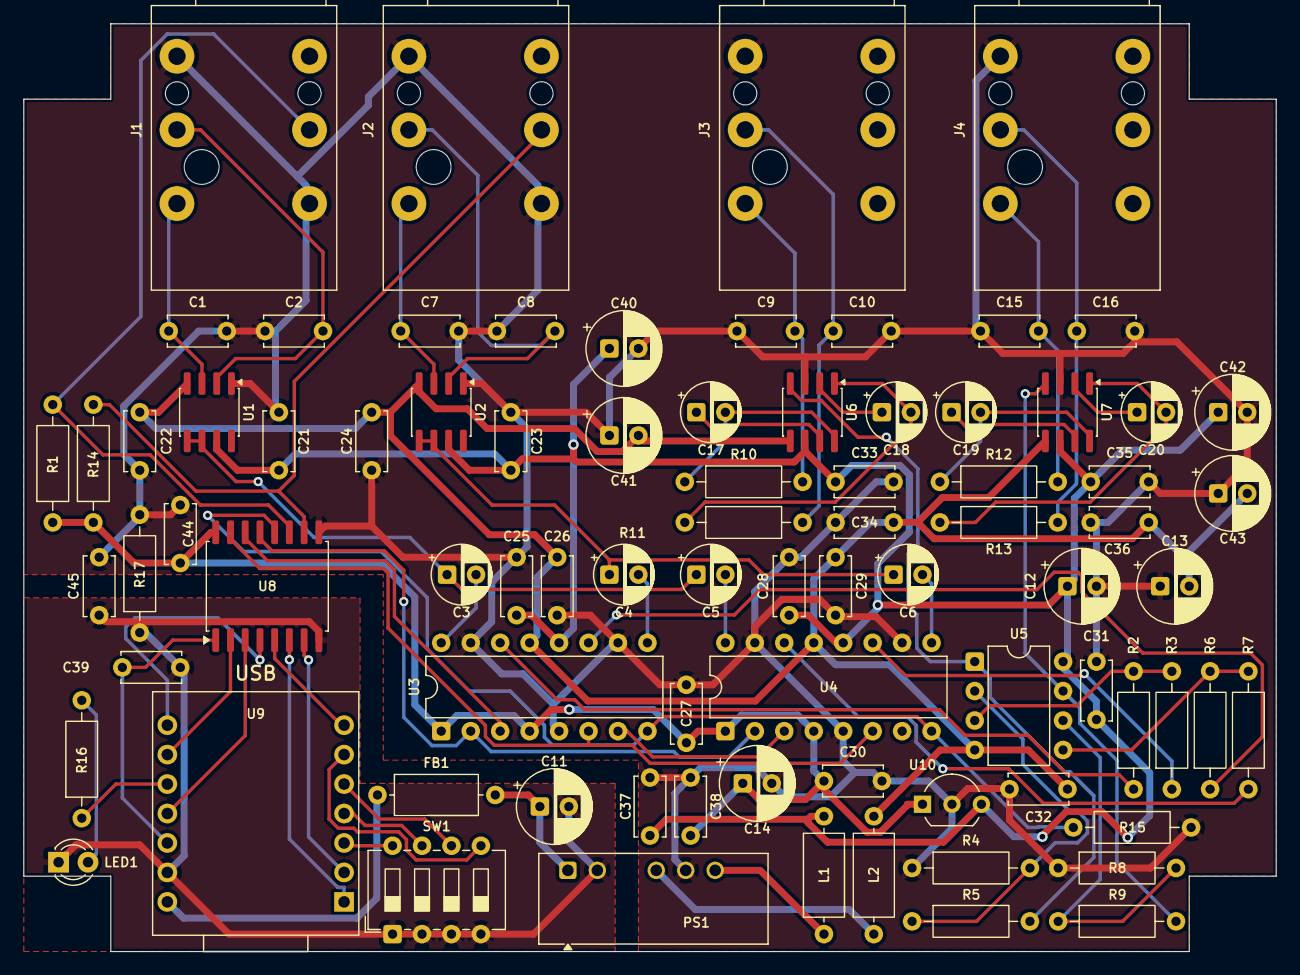
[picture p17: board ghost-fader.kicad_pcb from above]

Board: 2 copper layers, 108.0 x 80.0 mm, 82 parts (0 on the bottom side), 61 nets.

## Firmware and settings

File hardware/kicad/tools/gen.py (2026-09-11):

#!/usr/bin/env python3
"""Generate the Ghost Fader KiCad 9 schematic (root + 5 sheets), symbol lib and footprints."""
import sys, os, math, uuid, json
sys.path.insert(0, os.path.dirname(__file__))
from sexp import parse, dump, libsym, pins as sympins, Q

OUT = sys.argv[1] if len(sys.argv) > 1 else 'out'
KLIB = '/Applications/KiCad/KiCad.app/Contents/SharedSupport/symbols/'
PROJECT = 'ghost-fader'
DATE = '2026-09-09'
REV = 'D'
G = 2.54

def U(): return str(uuid.uuid4())
def g(n): return round(n * G, 4)

# ---------------------------------------------------------------- symbols
def pin(num, name, x, y, rot, etype='passive', length=2.54):
    return ['pin', etype, 'line', ['at', f'{x:g}', f'{y:g}', f'{rot:g}'], ['length', f'{length:g}'],
            ['name', Q(name), ['effects', ['font', ['size', '1.27', '1.27']]]],
            ['number', Q(num), ['effects', ['font', ['size', '1.27', '1.27']]]]]

def prop(name, val, x=0, y=0, hide=False, justify=None):
    eff = ['effects', ['font', ['size', '1.27', '1.27']]]
    if justify: eff.append(['justify', justify])
    if hide: eff.append(['hide', 'yes'])
    return ['property', Q(name), Q(val), ['at', f'{x:g}', f'{y:g}', '0'], eff]

BOX = {}   # GhostFader box symbols: (hw, hh)
def boxsym(name, refpfx, w, h, pinlist, desc, units=1):
    """pinlist: (num, name, side, pos, etype). side L/R/T/B, pos = offset along the side (mm, lib coords, y up)."""
    hw, hh = w / 2, h / 2
    s = ['symbol', Q(name), ['pin_names', ['offset', '1.016']], ['exclude_from_sim', 'no'], ['in_bom', 'yes'], ['on_board', 'yes'],
         prop('Reference', refpfx, -hw, hh + 1.27, justify='left'), prop('Value', name, hw, -hh - 1.27, justify='right'),
         prop('Footprint', '', hide=True), prop('Datasheet', '', hide=True), prop('Description', desc, hide=True)]
    body = ['symbol', Q(f'{name}_0_1'), ['rectangle', ['start', f'{-hw:g}', f'{hh:g}'], ['end', f'{hw:g}', f'{-hh:g}'],
            ['stroke', ['width', '0.254'], ['type', 'default']], ['fill', ['type', 'background']]]]
    s.append(body)
    u = ['symbol', Q(f'{name}_1_1')]
    for num, pname, side, pos, et in pinlist:
        if side == 'L': u.append(pin(num, pname, -hw - 2.54, pos, 0, et))
        elif side == 'R': u.append(pin(num, pname, hw + 2.54, pos, 180, et))
        elif side == 'T': u.append(pin(num, pname, pos, hh + 2.54, 270, et))
        elif side == 'B': u.append(pin(num, pname, pos, -hh - 2.54, 90, et))
    s.append(u)
    BOX[f'GhostFader:{name}'] = (hw, hh)
    return s

CUSTOM = {}
CUSTOM['THAT1246'] = boxsym('THAT1246', 'U', 15.24, 15.24, [
    ('2', 'In-', 'L', 2.54, 'input'), ('3', 'In+', 'L', -2.54, 'input'),
    ('6', 'Vout', 'R', 2.54, 'output'), ('5', 'Sense', 'R', -2.54, 'input'), ('8', 'NC', 'R', -5.08, 'no_connect'),
    ('1', 'Ref', 'B', -2.54, 'input'), ('4', 'Vee', 'B', 2.54, 'power_in'), ('7', 'Vcc', 'T', 0, 'power_in')],
    'THAT 1246 balanced line receiver, -6 dB, SO-8')
CUSTOM['THAT1646'] = boxsym('THAT1646', 'U', 15.24, 15.24, [
    ('4', 'In', 'L', 0, 'input'),
    ('8', 'Out+', 'R', 5.08, 'output'), ('7', 'Sns+', 'R', 2.54, 'input'), ('2', 'Sns-', 'R', -2.54, 'input'), ('1', 'Out-', 'R', -5.08, 'output'),
    ('3', 'Gnd', 'B', -2.54, 'power_in'), ('5', 'Vee', 'B', 2.54, 'power_in'), ('6', 'Vcc', 'T', 0, 'power_in')],
    'THAT 1646 OutSmarts balanced line driver, +6 dB, SO-8')
CUSTOM['PGA2310'] = boxsym('PGA2310', 'U', 20.32, 25.4, [
    ('16', 'VINL', 'L', 10.16, 'input'), ('9', 'VINR', 'L', 5.08, 'input'),
    ('1', 'ZCEN', 'L', 0, 'input'), ('2', '~{CS}', 'L', -2.54, 'input'), ('3', 'SDI', 'L', -5.08, 'input'),
    ('6', 'SCLK', 'L', -7.62, 'input'), ('8', '~{MUTE}', 'L', -10.16, 'input'),
    ('14', 'VOUTL', 'R', 10.16, 'output'), ('11', 'VOUTR', 'R', 5.08, 'output'), ('7', 'SDO', 'R', -7.62, 'output'),
    ('12', 'VA+', 'T', -5.08, 'power_in'), ('4', 'VD+', 'T', 5.08, 'power_in'),
    ('15', 'AGNDL', 'B', -7.62, 'power_in'), ('10', 'AGNDR', 'B', -2.54, 'power_in'), ('5', 'DGND', 'B', 2.54, 'power_in'), ('13', 'VA-', 'B', 7.62, 'power_in')],
    'TI PGA2310 stereo audio volume control, +/-15 V max analog, SPI, DIP-16')
CUSTOM['TBA2_Dual'] = boxsym('TBA2_Dual', 'PS', 20.32, 15.24, [
    ('1', '+Vin', 'L', 5.08, 'power_in'), ('2', '-Vin', 'L', -5.08, 'power_in'),
    ('6', '+Vout', 'R', 5.08, 'power_out'), ('5', 'Common', 'R', 0, 'power_out'), ('4', '-Vout', 'R', -5.08, 'power_out')],
    'TRACO TBA 2 series isolated 2 W unregulated DC-DC, dual output, SIP-7 (pins 3, 7 absent)')
CUSTOM['ISO7762F'] = boxsym('ISO7762F', 'U', 20.32, 25.4, [
    ('1', 'VCC1', 'L', 10.16, 'power_in'), ('2', 'INA', 'L', 5.08, 'input'), ('3', 'INB', 'L', 2.54, 'input'), ('4', 'INC', 'L', 0, 'input'), ('5', 'IND', 'L', -2.54, 'input'),
    ('6', 'OUTE', 'L', -5.08, 'output'), ('7', 'OUTF', 'L', -7.62, 'output'), ('8', 'GND1', 'L', -10.16, 'power_in'),
    ('16', 'VCC2', 'R', 10.16, 'power_in'), ('15', 'OUTA', 'R', 5.08, 'output'), ('14', 'OUTB', 'R', 2.54, 'output'), ('13', 'OUTC', 'R', 0, 'output'), ('12', 'OUTD', 'R', -2.54, 'output'),
    ('11', 'INE', 'R', -5.08, 'input'), ('10', 'INF', 'R', -7.62, 'input'), ('9', 'GND2', 'R', -10.16, 'power_in')],
    'TI ISO7762F six-channel digital isolator, 4 forward / 2 reverse, fail-safe low outputs, SOIC-16 wide (DW)')
CUSTOM['L78L05'] = boxsym('L78L05', 'U', 12.7, 7.62, [
    ('3', 'VI', 'L', 0, 'power_in'), ('1', 'VO', 'R', 0, 'power_out'), ('2', 'GND', 'B', 0, 'power_in')],
    '100 mA 5 V linear regulator, TO-92 (1 = out, 2 = gnd, 3 = in)')
# Seeed XIAO RP2040. Pin numbers follow Seeed's footprint: 1-7 down the left row from the USB end (D0-D6),
# 8-14 up the right row from the far end (D7-D10, 3V3, GND, 5V), so 14 is opposite 1 at the USB end.
xleft = [('1', 'D0/GP26'), ('2', 'D1/GP27'), ('3', 'D2/GP28'), ('4', 'D3/GP29'), ('5', 'D4/SDA/GP6'), ('6', 'D5/SCL/GP7'), ('7', 'D6/TX/GP0')]
xright = [('14', '5V'), ('13', 'GND'), ('12', '3V3'), ('11', 'D10/MOSI/GP3'), ('10', 'D9/MISO/GP4'), ('9', 'D8/SCK/GP2'), ('8', 'D7/RX/GP1')]
xpins = [(num, n, 'L', 7.62 - i * 2.54, 'bidirectional') for i, (num, n) in enumerate(xleft)]
xpins += [(num, n, 'R', 7.62 - i * 2.54, {'5V': 'power_out', 'GND': 'power_in', '3V3': 'power_out'}.get(n, 'bidirectional')) for i, (num, n) in enumerate(xright)]
CUSTOM['XIAO_RP2040'] = boxsym('XIAO_RP2040', 'U', 33.02, 20.32, xpins,
    'Seeed Studio XIAO RP2040: USB-C, RP2040, 11 GPIO. Pin numbers as on the Seeed footprint (1-7 left row from the USB end, 8-14 right row from the far end).')

def copysym(lib, name, newname=None, value=None):
    s = libsym(KLIB + lib + '.kicad_sym', name)
    s = json.loads(json.dumps(s))  # deep copy (loses Q) -> re-mark quoted strings below
    def requote(e):
        if isinstance(e, list): return [requote(x) for x in e]
        return e
    s = requote(s)
    # deep copy lost Q types; re-parse via dump of original instead
    s = parse(dump(libsym(KLIB + lib + '.kicad_sym', name)))[0]
    base = name
    if newname:
        for e in s:
            if isinstance(e, list) and e[0] == 'symbol' and str(e[1]).startswith(base + '_'):
                e[1] = Q(newname + str(e[1])[len(base):])
        s[1] = Q(newname); base = newname
    if value:
        for e in s:
            if isinstance(e, list) and e[0] == 'property' and e[1] == 'Value': e[2] = Q(value)
    return lib, base, s

LIBSYMS = {}   # lib_id -> sexp
for lib, name in [('Device', 'R'), ('Device', 'C'), ('Device', 'C_Polarized'), ('Device', 'L'), ('Device', 'FerriteBead'), ('Device', 'LED'),
                  ('Switch', 'SW_DIP_x04'), ('Connector_Audio', 'AudioJack3_SwitchTR'),
                  ('power', 'GND'), ('power', '+12V'), ('power', '-12V'), ('power', '+5V'), ('power', '+5VA'), ('power', '+3V3'), ('power', 'PWR_FLAG')]:
    _, base, s = copysym(lib, name)
    LIBSYMS[f'{lib}:{base}'] = s
_, base, s = copysym('Amplifier_Operational', 'LM2904', newname='OPA2134', value='OPA2134')
_own = parse(dump(libsym(KLIB + 'Amplifier_Operational.kicad_sym', 'OPA2134')))[0]
_props = {e[1]: e for e in _own if isinstance(e, list) and e[0] == 'property'}
s = [e for e in s if not (isinstance(e, list) and e[0] == 'property')]
for i, e in enumerate(_own):
    if isinstance(e, list) and e[0] == 'property': s.insert(len([x for x in s if not (isinstance(x, list) and x[0] == 'symbol')]), e)
CUSTOM['OPA2134'] = s   # LM2904 drawing + OPA2134 properties, kept in the project library
# GND_USB: the USB-side ground (XIAO, USB-C shell, isolator side 1, DC-DC input). Same drawing as GND, its own net.
_, _, s = copysym('power', 'GND', newname='GND_USB', value='GND_USB')
for e in s:
    if isinstance(e, list) and e[0] == 'property' and e[1] == 'Description': e[2] = Q('Power symbol creates a global label with name "GND_USB", the USB-side ground')
CUSTOM['GND_USB'] = s
LIBSYMS_WRITE_EXTRA = {}
for k, v in CUSTOM.items():
    LIBSYMS[f'GhostFader:{k}'] = v

PINPOS = {}  # lib_id -> {(unit, num): (x, y)}
PINLIST = {}  # lib_id -> [(unit, num, x, y)]
PINUNITS = {}
for k, s in LIBSYMS.items():
    d = {}; lst = []
    for unit, num, name, et, x, y, rot, ln in sympins(s):
        d[(int(unit), num)] = (x, y)
        d.setdefault((0, num), (x, y))
        lst.append((int(unit), num, x, y))
    PINPOS[k] = d; PINLIST[k] = lst; PINUNITS[k] = len({u for u, *_ in lst if u != 0})

FOOTPRINTS = {
    'R': 'Resistor_THT:R_Axial_DIN0207_L6.3mm_D2.5mm_P10.16mm_Horizontal',
    'C': 'Capacitor_THT:C_Disc_D5.0mm_W2.5mm_P5.00mm',
    'CNP': 'Capacitor_THT:CP_Radial_D5.0mm_P2.50mm',
    'CP': 'Capacitor_THT:CP_Radial_D6.3mm_P2.50mm',
    'L': 'Inductor_THT:L_Axial_L7.0mm_D3.3mm_P10.16mm_Horizontal_Fastron_MICC',
    'LED': 'LED_THT:LED_D3.0mm',
    'DIP4': 'Button_Switch_THT:SW_DIP_SPSTx04_Slide_6.7x11.72mm_W7.62mm_P2.54mm_LowProfile',
    'DIP16': 'Package_DIP:DIP-16_W7.62mm',
    'DIP8': 'Package_DIP:DIP-8_W7.62mm',
    'SO8': 'Package_SO:SOIC-8_3.9x4.9mm_P1.27mm',
    'SO16W': 'Package_SO:SOIC-16W_7.5x10.3mm_P1.27mm',
    'TO92': 'Package_TO_SOT_THT:TO-92_Inline_Wide',
    'XIAO': 'GhostFader:XIAO_RP2040_THT',
    'TBA2': 'Converter_DCDC:Converter_DCDC_TRACO_TBA2-xxxx_Dual_THT',
    'JACK': 'Connector_Audio:Jack_6.35mm_Neutrik_NRJ6HF_Horizontal',
}

def symbbox(lib_id, unit):
    xs, ys = [], []
    for e in LIBSYMS[lib_id]:
        if not (isinstance(e, list) and e[0] == 'symbol'): continue
        u = int(str(e[1]).split('_')[-2])
        if u not in (0, unit): continue
        for gph in e:
            if not isinstance(gph, list): continue
            if gph[0] == 'rectangle':
                for k in ('start', 'end'):
                    v = [x for x in gph if isinstance(x, list) and x[0] == k][0]; xs.append(float(v[1])); ys.append(float(v[2]))
            elif gph[0] == 'polyline':
                pts = [x for x in gph if isinstance(x, list) and x[0] == 'pts'][0]
                for xy in pts[1:]: xs.append(float(xy[1])); ys.append(float(xy[2]))
            elif gph[0] == 'circle':
                c = [x for x in gph if isinstance(x, list) and x[0] == 'center'][0]; r = float([x for x in gph if isinstance(x, list) and x[0] == 'radius'][0][1])
                xs += [float(c[1]) - r, float(c[1]) + r]; ys += [float(c[2]) - r, float(c[2]) + r]
            elif gph[0] == 'arc':
                for k in ('start', 'mid', 'end'):
                    v = [x for x in gph if isinstance(x, list) and x[0] == k][0]; xs.append(float(v[1])); ys.append(float(v[2]))
    if not xs: return (-1.27, -1.27, 1.27, 1.27)
    return (min(xs), min(ys), max(xs), max(ys))

# ---------------------------------------------------------------- sheet builder
class Part:
    def __init__(self, sheet, lib_id, ref, value, x, y, rot=0, mirror=None, unit=1, fp='', hide_value=False):
        self.sheet, self.lib_id, self.ref, self.value = sheet, lib_id, ref, value
        self.x, self.y, self.rot, self.mirror, self.unit, self.fp = x, y, rot, mirror, unit, fp
        self.uuid = U(); self.hide_value = hide_value
    def xf(self, px, py):
        t = math.radians(self.rot); c, s = round(math.cos(t)), round(math.sin(t))
        rx, ry = px * c - py * s, px * s + py * c
        if self.mirror == 'x': ry = -ry
        if self.mirror == 'y': rx = -rx
        return round(self.x + rx, 4), round(self.y - ry, 4)
    def p(self, num):
        d = PINPOS[self.lib_id]
        key = (self.unit, str(num)) if (self.unit, str(num)) in d else (0, str(num))
        return self.xf(*d[key])
    def fields(self):
        """Return (ref_at, ref_just, val_at, val_just, angle, hide_value)."""
        x, y, rot = self.x, self.y, self.rot
        ang = {0: 0, 90: 90, 180: 0, 270: 90}[rot]
        lib = self.lib_id
        if lib.startswith('power:') or lib == 'GhostFader:GND_USB':
            name = self.value
            up = (rot == 0) != (name in ('GND', 'GND_USB'))
            vy = y - 3.81 if up else y + 3.81
            return ((x, y), 'left', (x, vy), 'center', 0, name == 'PWR_FLAG')
        if lib in BOX and not lib.endswith('OPA2134'):
            hw, hh = BOX[lib]
            return ((x + hw - 2.54, y - hh - 3.81), 'left', (x + hw - 2.54, y - hh - 1.27), 'left', 0, False)
        if lib.endswith('OPA2134'):
            if self.unit == 3: return ((x + 2.54, y - 1.27), 'left', (x + 2.54, y + 1.27), 'left', 0, False)
            return ((x - 5.08, y - 6.35), 'left', (x - 5.08, y + 6.35), 'left', 0, False)
        x0, y0, x1, y1 = symbbox(lib, self.unit)
        corners = [self.xf(px, py) for px, py in ((x0, y0), (x1, y0), (x0, y1), (x1, y1))]
        bx0, bx1 = min(c[0] for c in corners), max(c[0] for c in corners)
        by0, by1 = min(c[1] for c in corners), max(c[1] for c in corners)
        two_pin = lib.split(':')[1] in ('R', 'C', 'C_Polarized', 'L', 'FerriteBead', 'LED')
        horizontal = two_pin and abs(self.p('1')[0] - self.p('2')[0]) > abs(self.p('1')[1] - self.p('2')[1])
        if two_pin and not horizontal:
            return ((bx1 + 1.27, y - 1.27), 'left', (bx1 + 1.27, y + 1.27), 'left', ang, False)
        if two_pin:
            return ((x, by0 - 1.27), 'center', (x, by1 + 1.27), 'center', ang, False)
        return ((bx0, by0 - 1.27), 'left', (bx0, by1 + 1.27), 'left', ang, False)
    def sexp(self, path):
        d = PINPOS[self.lib_id]
        nums = sorted({n for (u, n) in d if u in (0, self.unit)} if not self.lib_id.endswith('OPA2134') else {n for (u, n) in d if u == self.unit}, key=lambda s: (len(s), s))
        m = f' (mirror {self.mirror})' if self.mirror else ''
        lines = [f'(symbol (lib_id "{self.lib_id}") (at {self.x:g} {self.y:g} {self.rot:g}){m} (unit {self.unit}) (exclude_from_sim no) (in_bom {"no" if self.ref.startswith("#") else "yes"}) (on_board {"no" if self.ref.startswith("#") else "yes"}) (dnp no) (uuid "{self.uuid}")']
        (rx, ry), rj, (vx, vy), vj, ang, hv = self.fields()
        hv = hv or self.hide_value
        hvs = ' (hide yes)' if hv else ''
        hr = ' (hide yes)' if self.ref.startswith('#') else ''
        js = lambda j: '' if j == 'center' else f' (justify {j})'
        lines.append(f'  (property "Reference" "{self.ref}" (at {rx:g} {ry:g} {ang}) (effects (font (size 1.27 1.27)){js(rj)}{hr}))')
        lines.append(f'  (property "Value" "{self.value}" (at {vx:g} {vy:g} {ang}) (effects (font (size 1.27 1.27)){js(vj)}{hvs}))')
        lines.append(f'  (property "Footprint" "{self.fp}" (at {self.x:g} {self.y:g} 0) (effects (font (size 1.27 1.27)) (hide yes)))')
        lines.append(f'  (property "Datasheet" "" (at {self.x:g} {self.y:g} 0) (effects (font (size 1.27 1.27)) (hide yes)))')
        for n in nums:
            lines.append(f'  (pin "{n}" (uuid "{U()}"))')
        lines.append(f'  (instances (project "{PROJECT}" (path "{path}" (reference "{self.ref}") (unit {self.unit}))))')
        lines.append(')')
        return '\n'.join(lines)
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

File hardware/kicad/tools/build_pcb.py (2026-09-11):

#!/usr/bin/env python3
"""Build ghost-fader.kicad_pcb from the schematic netlist: footprints, nets, placement, outline, ground pours.

Run with KiCad's bundled Python (it needs the pcbnew module):
  kicad-cli sch export netlist --format kicadsexpr -o /tmp/gf.net ghost-fader.kicad_sch
  /Applications/KiCad/KiCad.app/Contents/Frameworks/Python.framework/Versions/Current/bin/python3 tools/build_pcb.py /tmp/gf.net

Board: 108 x 80 mm, 2 layers, for a Hammond 1590BB (inside ~112 x 86 mm, lid-screw bosses on 103.5 x 78 mm
centres, cleared by 7.5 x 6.5 mm corner notches). Jacks on the rear edge (y = 0), XIAO USB-C on the front edge
(y = 80). Coordinates below are mm, origin top-left, y down. Signal flow: jacks -> receivers (y ~33) ->
coupling caps (y ~47) -> PGA2310s (y ~53-61) -> summers/drivers -> output jacks; DC-DC at the front centre,
input receivers top-left, so the converter is as far from the receivers as the board allows.

Rev D ground split: the front-left corner (x 0-29 for y > 49.5, widening to x 0-51 for y > 65.5) is the USB
ground island (GND_USB): XIAO, DIP switch, LED, ferrite, reservoir cap, isolator side 1 and the DC-DC input
pins. Everything else is on the audio ground. A 2 mm gap with no copper separates the two pours; only U8
(isolator, across the top of the island) and PS1 (DC-DC, across its right edge) straddle the gap, plus the
barrier parts C45 and R17. A rule area over the gap keeps the router out of it.
"""
import sys, os
sys.path.insert(0, os.path.dirname(__file__))
from sexp import parse
import pcbnew
from pcbnew import VECTOR2I, EDA_ANGLE, DEGREES_T

HERE = os.path.dirname(os.path.abspath(__file__))
PROJ = os.path.dirname(HERE)
NETFILE = sys.argv[1]
OUT = sys.argv[2] if len(sys.argv) > 2 else os.path.join(PROJ, 'ghost-fader.kicad_pcb')
FPDIR = '/Applications/KiCad/KiCad.app/Contents/SharedSupport/footprints'

W, H = 108.0, 80.0          # board outline
NX, NY = 7.5, 6.5           # corner notch (clears the 1590BB lid-screw bosses)
# ground split: island polygon (GND_USB pour), audio polygon (GND pour) and the 2 mm gap between them (rule area)
ISLAND = [(0, 49.5), (29, 49.5), (29, 65.5), (51, 65.5), (51, H), (0, H)]
AUDIO = [(NX, 0), (W - NX, 0), (W - NX, NY), (W, NY), (W, H - NY), (W - NX, H - NY), (W - NX, H), (53, H), (53, 63.5), (31, 63.5), (31, 47.5), (0, 47.5), (0, NY), (NX, NY)]
GAP = [(0, 47.5), (31, 47.5), (31, 63.5), (53, 63.5), (53, H), (51, H), (51, 65.5), (29, 65.5), (29, 49.5), (0, 49.5)]

def mm(v): return pcbnew.FromMM(v)
def pt(x, y): return VECTOR2I(mm(x), mm(y))

# ---------------------------------------------------------------- placement: ref -> (x, y, rotation)
# Anchor is the footprint origin (pad 1 / T pad / body centre, as each library footprint defines it).
def jack(c): return (c - 5.79, 15.5, 90)      # nose points to the rear edge, T pad column at x = c - 5.79
PLACE = {
    # rear jacks, in L, in R, out L, out R
    'J1': jack(19), 'J2': jack(39), 'J3': jack(68), 'J4': jack(90),
    # RF caps at the jack pins
    'C1': (12.5, 26.5, 0), 'C2': (20.8, 26.5, 0), 'C7': (32.5, 26.5, 0), 'C8': (40.8, 26.5, 0),
    'C9': (61.5, 26.5, 0), 'C10': (69.8, 26.5, 0), 'C15': (82.5, 26.5, 0), 'C16': (90.8, 26.5, 0),
    # input receivers (inputs face the jacks) and their 100n
    'U1': (16, 33.5, 270), 'U2': (36, 33.5, 270),
    'C22': (10, 38.5, 90), 'C21': (22, 38.5, 90), 'C24': (30, 38.5, 90), 'C23': (42, 38.5, 90),
    # +/-12 V bulk, input end, in the gap between J2 and J3
    'C40': (50.5, 28, 0), 'C41': (50.5, 35.5, 0),
    # plug-sense pull-ups (audio side, +5VA) in the left column above the island
    'R1': (2.5, 43, 90), 'R14': (6, 43, 90),
    # isolator across the top edge of the island: side 2 (audio) row at y 43.9, side 1 (USB) row at y 53.2
    'U8': (21, 48.5, 90), 'C44': (13.5, 46.5, 90), 'C39': (8.5, 55.5, 0),
    # barrier parts, both straddling the gap in the left column (the SPI lines leave U8 on its right)
    'R17': (10, 52.5, 90), 'C45': (6.5, 51, 90),
    # coupling caps into the PGAs and the PGA +/-12 V 100n
    'C3': (36.5, 47.5, 0), 'C25': (42.5, 51, 90), 'C26': (46, 51, 90), 'C4': (50.5, 47.5, 0),
    'C5': (58, 47.5, 0), 'C28': (66, 51, 90), 'C29': (70, 51, 90), 'C6': (75, 47.5, 0),
    # PGA2310s, analog pins on top (y 53.4), digital pins below (y 61); a +5VA 100n between them
    'U3': (36, 61, 90), 'U4': (60.5, 61, 90), 'C27': (57.14, 62, 90),
    # USB island: XIAO across the front edge, USB-C face flush with it; DIP switch right of it, LED in the left column
    'U9': (20, 68.1, 180), 'SW1': (31.8, 78.5, 90), 'LED1': (3, 72.3, 0),
    # island: LED resistor in the left column, ferrite and reservoir right of the XIAO; DC-DC straddles the island's right edge (x 52)
    'R16': (5, 68.5, 90), 'FB1': (30.5, 66.5, 0), 'C11': (44.5, 67.5, 0), 'PS1': (46.92, 73, 90),
    # audio side of the front strip: 78L05 caps, +5VA bulk, U4 VD+ 100n, rail filters, 78L05, op-amp V- 100n, mute pull-down; C12/C13 up by the summer
    'C37': (54, 70, 90), 'C38': (57.5, 70, 90), 'C14': (62, 65.5, 0), 'C30': (69, 65.3, 0), 'L1': (69, 78.5, 90), 'L2': (73.3, 78.5, 90),
    'U10': (77.5, 67.3, 0), 'C32': (85, 66, 0), 'R15': (90.5, 69.3, 0), 'C12': (90, 48.5, 0), 'C13': (98, 48.5, 0),
    # summing resistors from the PGA outputs, op-amp, feedback/ground resistors, op-amp 100n
    'R2': (95.7, 66, 90), 'R3': (99, 66, 90), 'R6': (102.3, 66, 90), 'R7': (105.6, 66, 90),
    'U5': (82, 55, 0), 'R4': (76.6, 72.8, 0), 'R5': (76.6, 77.4, 0), 'R8': (89.2, 72.8, 0), 'R9': (89.2, 77.4, 0),
    'C31': (92.5, 60, 90),
    # output drivers under J3/J4 with sense caps either side, build-out resistors and 100n below
    'C17': (58, 33.5, 0), 'U6': (68, 33.5, 270), 'C18': (74, 33.5, 0),
    'C19': (80, 33.5, 0), 'U7': (90, 33.5, 270), 'C20': (96, 33.5, 0),
    'R10': (57, 39.5, 0), 'R11': (57, 43, 0), 'C33': (70, 39.5, 0), 'C34': (70, 43, 0),
    'R12': (79, 39.5, 0), 'R13': (79, 43, 0), 'C35': (92, 39.5, 0), 'C36': (92, 43, 0),
    # +/-12 V bulk, output end
    'C42': (103, 33.5, 0), 'C43': (103, 40.5, 0),
}
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

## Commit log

2026-09-03 Add Ghost Fader schematic package and parts list
    USB-MIDI controlled volume and pan for two balanced TRS line channels:
    THAT 1246 receivers, a 2x2 PGA2310 gain matrix, OPA1642 summers and
    THAT 1646 balanced drivers, driven by a bus-powered Teensy 4.0.
    Includes block diagram, five schematic sheets, level and USB power
    budgets, MIDI CC map and a priced parts list.
    Claude-Session: https://claude.ai/code/session_0183fDBNezbxHgiTgTifXH9b
2026-09-06 Publish schematic as GitHub Pages site and clarify bus-only power
    Move hardware/ghost-fader.html to docs/index.html wrapped as a full HTML
    document so it serves from GitHub Pages. State explicitly that PS1 is a
    board-mounted DC-DC converter fed from USB, not an external supply.
    Claude-Session: https://claude.ai/code/session_01GgLjVSsknENymBQryvRAZ2
2026-09-07 Add full KiCad 9 schematic, project library, BOM and rendered sheets
    Five-sheet hierarchical schematic generated by hardware/kicad/tools/gen.py:
    real pin numbers from the PGA2310, THAT 1246/1646, OPA2134 and TMR 3
    datasheets, every bypass cap, 1646 sense caps, DIP packages. ERC passes
    clean and the netlist is checked pin-for-pin by tools/check.py.
    Sheets are embedded in the published page with a PDF and BOM.
    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
    [bom.csv, control.kicad_sch, ghost-fader.kicad_sch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]
2026-09-08 Add routed PCB layout, gerbers and PCB section on the site
    - ghost-fader.kicad_pcb: 2-layer 108 x 80 mm board for the Hammond 1590BB,
    corner notches for the lid-screw bosses, jacks on the rear edge, Teensy USB
    flush with the front edge, DC-DC front-centre. Ground pour both layers,
    0.6 mm power / 0.3 mm signal tracks. DRC clean with schematic parity.
    - tools/build_pcb.py (placement table, outline, pours, rules) and
    tools/route.py (Freerouting DSN/SES round trip) to regenerate the board.
    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
    [bom.csv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]
2026-09-08 Label every part on the silkscreen
    Reference designators now sit beside each part instead of under it:
    a per-part label table in build_pcb.py plus rules per footprint type
    (vertical discs and axials labelled beside/above, radial cans above or
    below). The summer block on the right was opened up so the resistor
    rows have room for labels; L2 and the R4/R5/R8/R9 rows shifted a
    little, C12/C13 moved up beside U5, R16 back to the left column.
    Re-routed, DRC still 0 errors; gerbers and site renders regenerated.
    Claude-Session: https://claude.ai/code/session_015P372fhz9Ee8MTRWGXMeho
    [ghost-fader-B_Cu.gbr, ghost-fader-B_Mask.gbr, ghost-fader-B_Paste.gbr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]
2026-09-08 Show the bare board on the site so the designators are readable
2026-09-09 Add a narrow in-line PCB for a Hammond 1455K1601 extrusion
    A second, independent board for the same schematic: 156 x 74.5 mm,
    inputs on the right end plate, outputs on the left, Teensy USB out of
    the middle of the rear edge, so the box sits in a signal chain like a
    pedal. Sized for the 1455K1601 (78 x 43 x 160 mm, 75 mm board slots);
    the board slides into the wall slots and hangs on the four jack nuts.
    - tools/build_pcb_narrow.py: placement table, plain outline, keep-out
    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
    [ghost-fader-narrow-B_Cu.gbr, ghost-fader-narrow-B_Mask.gbr, ghost-fader-narrow-B_Paste.gbr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]
2026-09-09 Make the 207 x 38 mm board the narrow PCB, replacing the 1455K one
    The slim board from #4 merged into #3's branch instead of main, so it
    never reached the site. This puts it on main under the narrow name and
    drops the 156 x 74.5 mm Hammond 1455K1601 board: one narrow board, the
    one as wide as two side-by-side jacks allow.
    - ghost-fader-narrow.kicad_pcb / .kicad_pro and tools/build_pcb_narrow.py
    are now the 207 x 38 mm board (silkscreen title says narrow).
    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
    [ghost-fader-narrow-B_Cu.gbr, ghost-fader-narrow-B_Mask.gbr, ghost-fader-narrow-B_Paste.gbr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]
2026-09-10 Rev C: XIAO RP2040 and Traco TBA 2-0522 replace the Teensy 4.0 and TMR 3
    Tier 1 cost-down, no change to the audio path. U9 becomes a Seeed XIAO
    RP2040 on header pins (USB-C, TinyUSB MIDI, its 5V pin is VBUS straight
    through), PS1 becomes a 2 W unregulated Traco TBA 2-0522 on KiCad's stock
    SIP-7 footprint. Rails are now +/-12 V: the +/-15 V TBA 2-0523 would pass
    the PGA2310's 16 V absolute maximum at light load. Parts cost drops from
    about $145 to about $110.
    - gen.py: TBA2_Dual and XIAO_RP2040 symbols, XIAO footprint (Seeed pin
    numbering, USB-C overhang drawn), control sheet rewired to D0-D10,
    power sheet and notes for the unregulated converter, +/-12V rails.
    - check.py: new U9 / PS1 pi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
    [bom.csv, control.kicad_sch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]
2026-09-10 Rev D: isolate the audio ground from USB
    Add a TI ISO7762FDW digital isolator on the four control lines and two
    plug-sense lines, a 78L05 that makes +5VA from +12 V for the PGA logic
    and the isolator's audio side, and a split ground: GND_USB (XIAO, USB-C,
    switch, LED, ferrite, reservoir, DC-DC input) and GND (everything audio).
    The two meet only through C45 (1 nF) and R17 (1 M) at PS1. The sense
    pull-ups drop from 1 M to 100 k for the isolator's input leakage.
    Both boards get two ground pours per layer with a 2 mm copper-free gap
    and a rule area that keeps the router out; U8 and PS1 straddle the gap.
    The 1590BB board's island is the front-left corner; the narrow board's
    is a pocket under th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
    [bom.csv, control.kicad_sch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]
